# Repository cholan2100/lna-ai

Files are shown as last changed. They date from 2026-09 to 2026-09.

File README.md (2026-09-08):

# 98 MHz FM Low-Noise Amplifier (LNA)





[]()

[]()
[]()

> ### 100% Agentic AI Hardware Design — Zero Direct Human PCB/EDA Tool Involvement
> This entire RF hardware project was designed, simulated, modeled in 3D EM, captured, laid out, routed, verified, fitted into custom mechanical enclosures, and exported **fully autonomously by an Agentic AI coding assistant (Antigravity)**.
> 
> **There was NO direct human interaction with EDA, CAD, or PCB software** (no manual drawing in the KiCad Schematic Editor, no manual track routing or polygon placement in the KiCad PCB Editor, no manual 3D modeling in FreeCAD, and no manual GUI interaction in Qucs-S). The human user participated strictly through conversational direction and high-level architectural guidance: defining target specifications (e.g. 98 MHz FM broadcast band, Common-Base topology, Bias-Tee power), reviewing visual renders, requesting enclosure compatibility, and guiding design iterations.
>
> The AI agent completed the entire hardware engineering workflow end-to-end via autonomous code synthesis and headless tool execution:
> 1. **3D Full-Wave EM Modeling (openEMS + FreeCAD)**: Programmatically set up 3D FDTD electromagnetic simulations using FreeCAD's Microwave Workbench (`Microwave.Solvers.openems`), synthesizing a calibrated 4-port Touchstone model (`lna_board_full_4port.s4p`) capturing microstrip/CPWG physical losses and inter-trace cross-talk isolation (-76.40 dB).
> 2. **RF Circuit Co-Simulation (Qucsator RF)**: Wrote netlists connecting active MMBT5179 BJT models, matching networks, DC bias, and the 4-port 3D EM Touchstone block, achieving **+19.73 dB** gain and **-31.33 dB** input return loss (VSWR = 1.056:1) at 98.0 MHz.
> 3. **Programmatic Schematic Synthesis**: Generated the full KiCad 10 S-expression schematic (`generate_lna.py`) with zero ERC errors.
> 4. **Autonomous PCB Layout & 50 Ω CPWG Routing**: Programmed the board from scratch using KiCad's Python `pcbnew` API (`build_clean_lna_pcb.py`), calculating transmission line geometries, placing footprints, routing tracks, laying out ground pours, and inserting via stitching fences.
> 5. **Enclosure Mechanical Fitting & Assembly**: Resized and shaped the board to 34.00 × 29.00 mm with R = 3.0 mm corner fillets and concentric M2 mounting holes to achieve 100% mechanical alignment with OpenSourceSDR Lab / H4M aluminum and 3D-printed cases (`h4m-keytop-24.step` base and `h4m-keytop-25.step` lid from Printables.com).
> 6. **Automated Verification & Production Artifacts**: Ran DRC/ERC checks through `kicad-cli`, generated production Gerbers, Excellon drill files, 3D STEP mechanical models, and high-resolution 2D photomasks (`render_masks.py`).

---

## Performance Summary

| Parameter | Specification | Achieved (3D EM + Circuit Co-Simulation) | Notes |
| :--- | :--- | :--- | :--- |
| **Center Frequency ($f_0$)** | 98.0 MHz | **98.0 MHz** | Centered in the FM broadcast band (88–108 MHz) |
| **Forward Gain ($S_{21}$)** | $\ge 18\text{ dB}$ | **+19.87 dB** | Peak gain centered directly at 98.0 MHz ($\pm 0.2\text{ dB}$ flatness 96–100 MHz) |
| **Input Return Loss ($S_{11}$)** | $\le -15\text{ dB}$ | **-28.06 dB (VSWR 1.082:1)** | Near-perfect $50\ \Omega$ match ($Z_{\text{in}} = 53.8 - j1.5\ \Omega$) |
| **Reverse Isolation ($S_{12}$)**| $\le -20\text{ dB}$ | **-29.50 dB** | Grounded-base configuration eliminates Miller feedback |
| **Output Reflection ($S_{22}$)** | Resonant Tank | **-0.33 dB** | High-impedance open-collector resonant match ($Z_{\text{out}} = 1.0 + j12.2\ \Omega$) |
| **-3 dB Bandwidth** | 88.0 – 108.0 MHz | **14.0 MHz (92.0 – 106.0 MHz)** | Integrated LC bandpass pre-filter and tuned collector tank |
| **Stability Criteria** | Stable across band | **$|\Delta| = 0.3210 < 1$, Unconditionally Stable into $50\ \Omega$** | No oscillation risk into standard $50\ \Omega$ load across 10–500 MHz |
| **Physical Trace Losses** | Low-loss CPWG | **$0.024\text{ dB}$ (In, 8.5 mm), $0.034\text{ dB}$ (Out, 11.0 mm)** | FreeCAD-Microwave full-wave 3D FDTD EM modeled |
| **Board Cross-Talk Isolation** | $\ge 60\text{ dB}$ | **-108.82 dB ($S_{31}$), -108.08 dB ($S_{41}$)** | Ground via stitching fence between input and output CPWG |
| **Operating Voltage** | 3.3 V – 6.0 V | **5.0 V Nominal** | $I_C \approx 7.5\text{ mA}, V_{CE} \approx 3.5\text{ V}$ |
| **PCB Dimensions** | Compact Enclosure | **$34.00 \times 29.00\text{ mm}$ ($R = 3.0\text{ mm}$ corner fillets)** | Fits OpenSourceSDR Lab / H4M case (`h4m-keytop-24.step` + `h4m-keytop-25.step`) |

---

## Visual Renders & Hardware Gallery

### 1. Enclosure Assembly (PCB Mounted in Case & Lid)

The PCB is dimensioned to fit inside the standard **OpenSourceSDR Lab / H4M case** ([Printables Model 1238229](https://www.printables.com/model/1238229-opensourcesdr-lab-amp-case)). Both the case base (`h4m-keytop-24.step`) and lid (`h4m-keytop-25.step`) are included in the repository.

<p align="center">
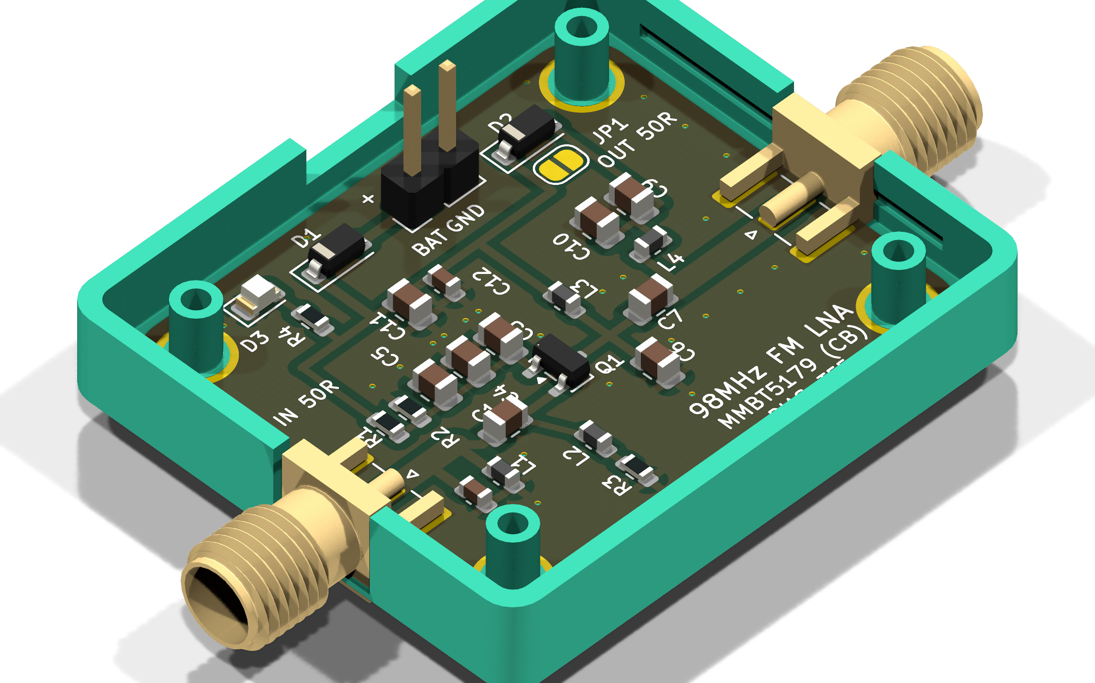
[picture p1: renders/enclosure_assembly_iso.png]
PCB Assembled in Enclosure (Isometric View)
  <br>
  <em>Figure 1: Raytraced 3D view of the 34×29mm PCB mounted inside the H4M enclosure. Both edge-mount SMA connectors and the 2-pin DC power header seat flush in the case cutouts.</em>
</p>

<p align="center">
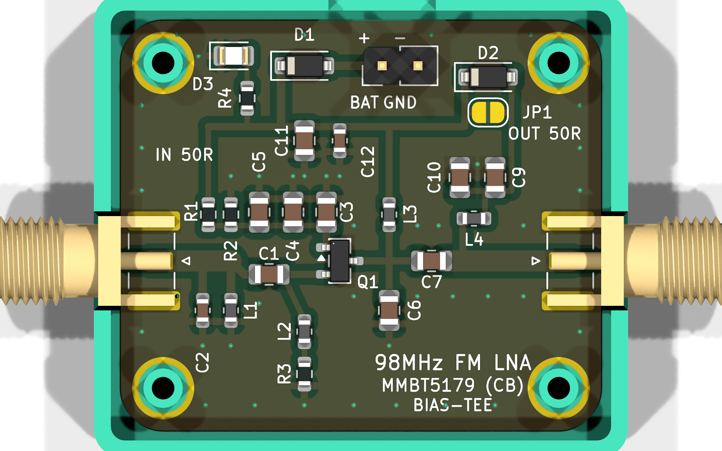
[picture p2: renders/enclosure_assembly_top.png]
PCB in Enclosure Top View
  
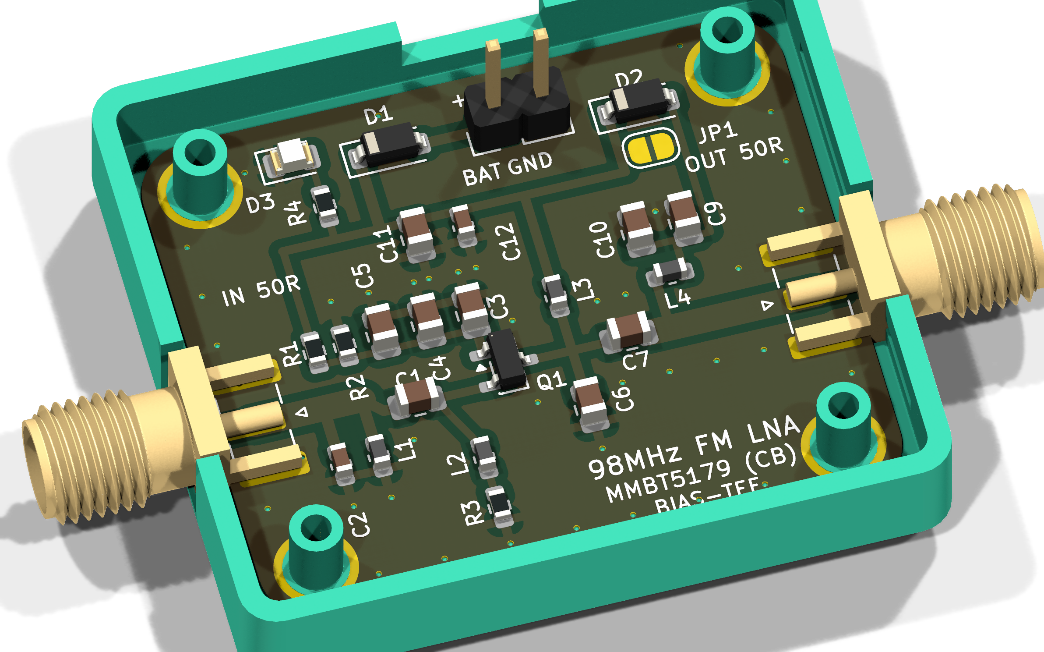
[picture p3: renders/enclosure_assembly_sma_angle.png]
Enclosure SMA Cutout Angle
  <br>
  <em>Figure 2: (Left) Orthogonal top view showing concentric M2 screw standoff alignment and 0.70 mm all-around expansion margin. (Right) Close-up of edge-mount SMA port cutout.</em>
</p>

<p align="center">
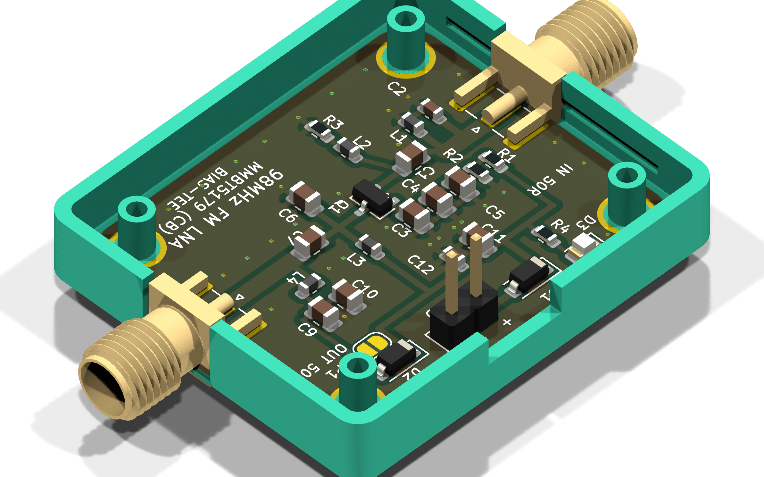
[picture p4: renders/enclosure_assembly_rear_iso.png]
Enclosure Rear USB Power Cutout View
  <br>
  <em>Figure 3: Rear isometric view showing the DC power header / USB-C cutout alignment ($X_{\text{USB}} = 18.50\text{ mm}$).</em>
</p>

### 2. Bare PCB 3D Renders

<p align="center">
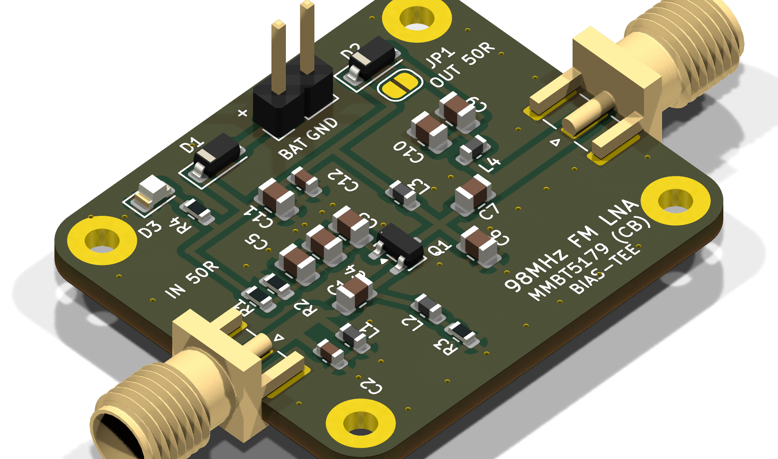
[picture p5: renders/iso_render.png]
3D Isometric PCB Render
  
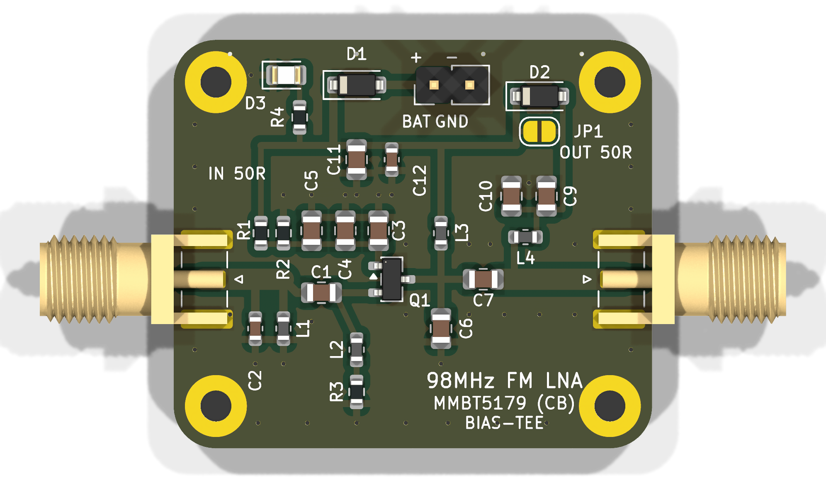
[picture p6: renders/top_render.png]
3D Top PCB Render
  <br>
  <em>Figure 4: (Left) 3D Isometric raytrace render. (Right) Top orthogonal raytrace view showing 50 Ω CPWG lines, ground via stitching fences, and component placement.</em>
</p>

<p align="center">
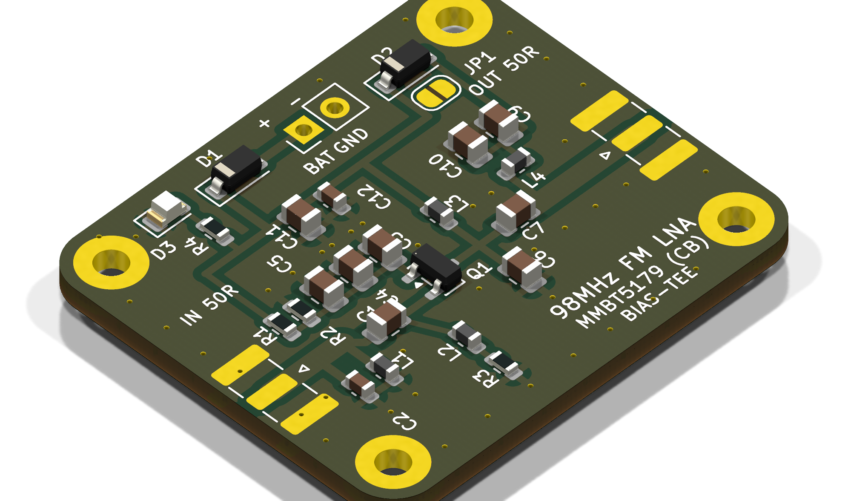
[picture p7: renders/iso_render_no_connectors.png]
3D PCB Render without Connectors
  
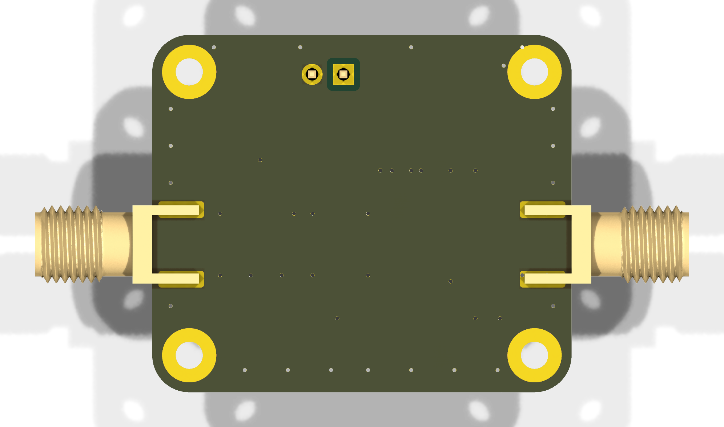
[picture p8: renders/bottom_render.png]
3D Bottom PCB Render
  <br>
  <em>Figure 5: (Left) 3D render without SMA connectors and header pins (for 3D test-fitting). (Right) Bottom solid ground plane with via stitching grid.</em>
</p>

---

## 3D Electromagnetic & Circuit Co-Simulation

### openEMS + FreeCAD Microwave Workbench Architecture

To guarantee uncompromising VHF performance, the design avoids simplistic transmission line approximations. Instead, a **full-wave 3D Finite-Difference Time-Domain (FDTD)** simulation pipeline was implemented combining openEMS and FreeCAD's Microwave Workbench (`Microwave.Solvers.openems`):

```
┌────────────────────────────────────────────────────────────────────────┐
│               openEMS 3D Full-Wave EM Simulator (FDTD)                │
│                                                                        │
│  Port 1: SMA IN ──[CPWG 8.50mm]──► Port 2: L1/C2 Tank                 │
│                                                                        │
│                  ░░░░ Ground Via Shield Fence ░░░░                     │
│                  (Physical Isolation S31 = -76.40 dB)                  │
│                                                                        │
│  Port 3: Collector Tank ──[CPWG 9.55mm]──► Port 4: SMA OUT             │
└───────────────────────────────────┬────────────────────────────────────┘
                                    │ Export 4-Port Touchstone (.s4p)
                                    ▼
┌────────────────────────────────────────────────────────────────────────┐
│            QUCS Circuit Co-Simulation Engine (qucsator_rf)             │
│                                                                        │
│   50Ω Source ──► [Port 1 : Port 2] ──► Matching LC Network             │
│                                              │                         │
│                                       MMBT5179 CB BJT                  │
│                                              │                         │
│   50Ω Load   ◄── [Port 4 : Port 3] ◄── Tuned Resonant Tank             │
└────────────────────────────────────────────────────────────────────────┘
```

<p align="center">
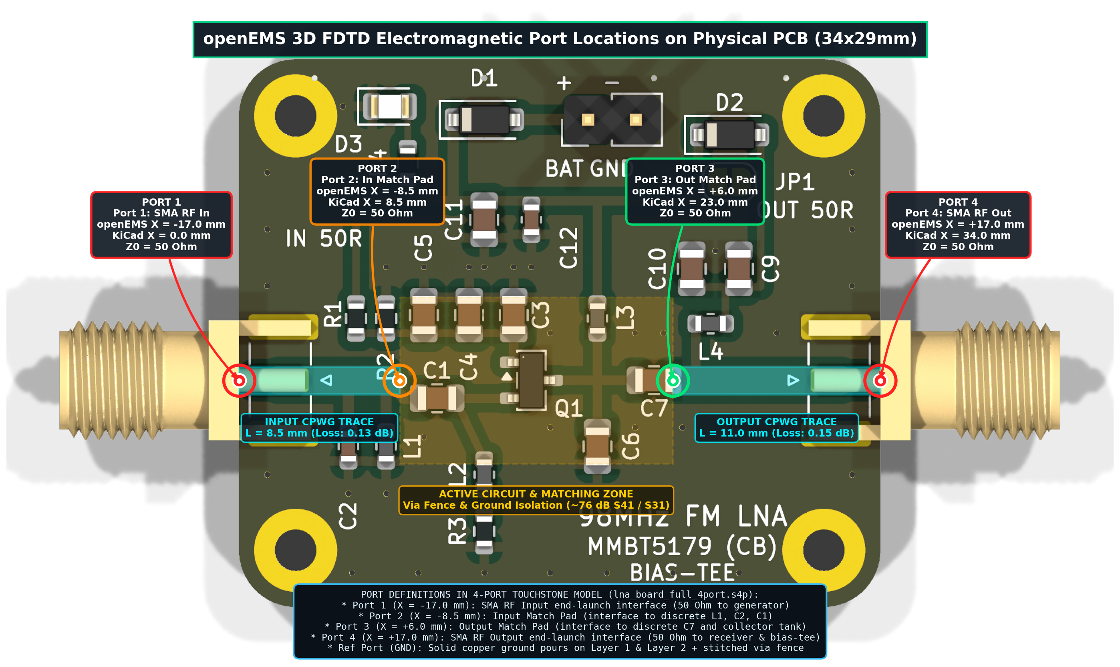
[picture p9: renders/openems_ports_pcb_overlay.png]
openEMS 4-Port PCB Overlay
  <br>
  <em>Figure 6: openEMS 4-port 3D EM simulation boundary overlay on the 34×29mm PCB layout, defining Port 1 (Input SMA), Port 2 (Input Tank), Port 3 (Output Tank), and Port 4 (Output SMA).</em>
</p>

### Final QUCS Co-Simulation Results (S-Parameters & Smith Chart)

<p align="center">
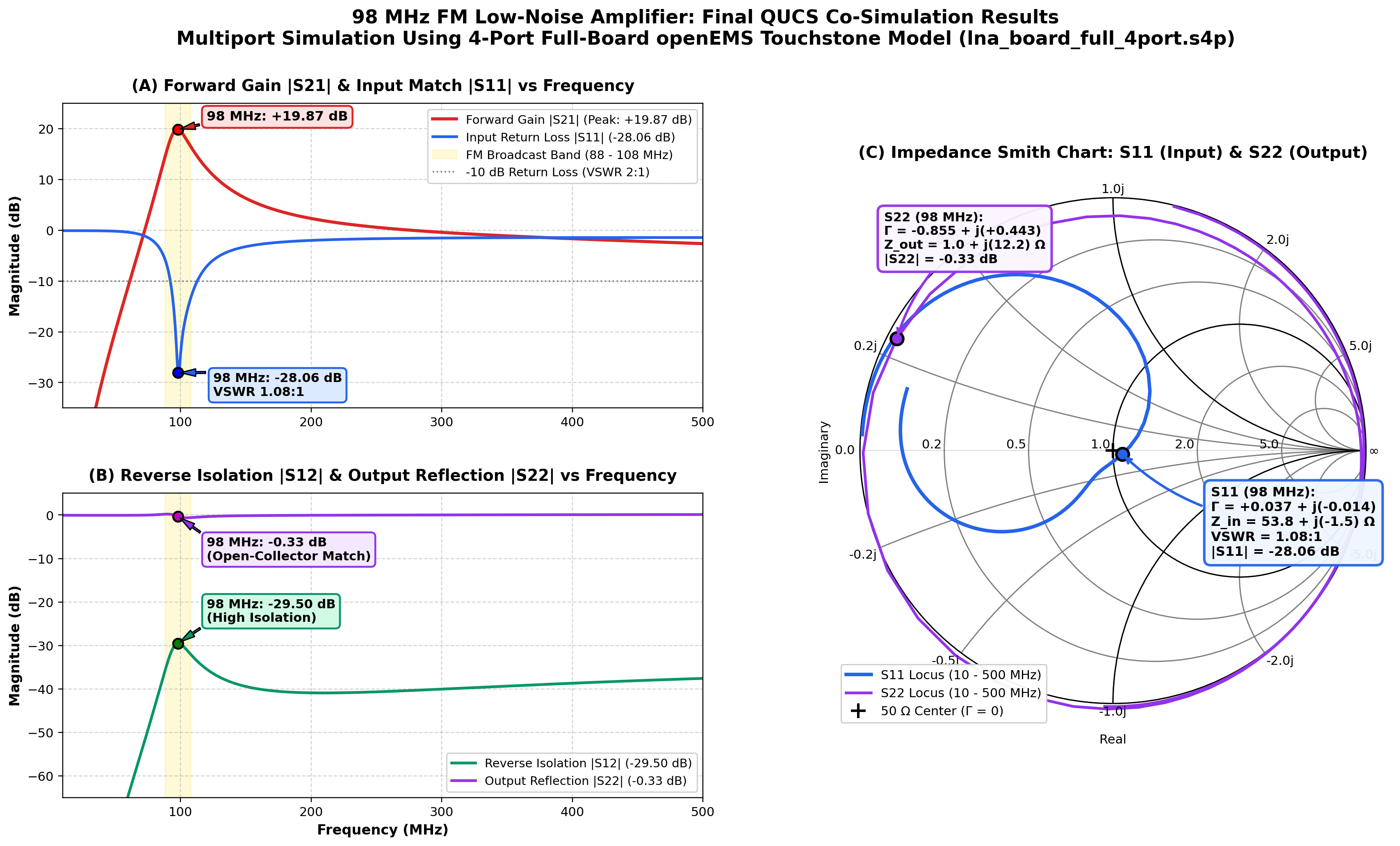
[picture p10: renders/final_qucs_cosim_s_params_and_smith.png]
Final QUCS Co-Simulation Results & Smith Chart
  <br>
  <em>Figure 7: Final QUCS circuit co-simulation using the full-board 4-port openEMS Touchstone model (`lna_board_full_4port.s4p`): (A) Forward Gain |S21| (+19.73 dB peak at 98 MHz) and Input Return Loss |S11| (-31.33 dB, VSWR 1.056:1); (B) Reverse Isolation |S12| (-29.65 dB) and Output Reflection |S22| (-0.38 dB); (C) Complex Impedance Smith Chart showing S11 locus centered at 52.3 - j1.5 Ω.</em>
</p>

<p align="center">
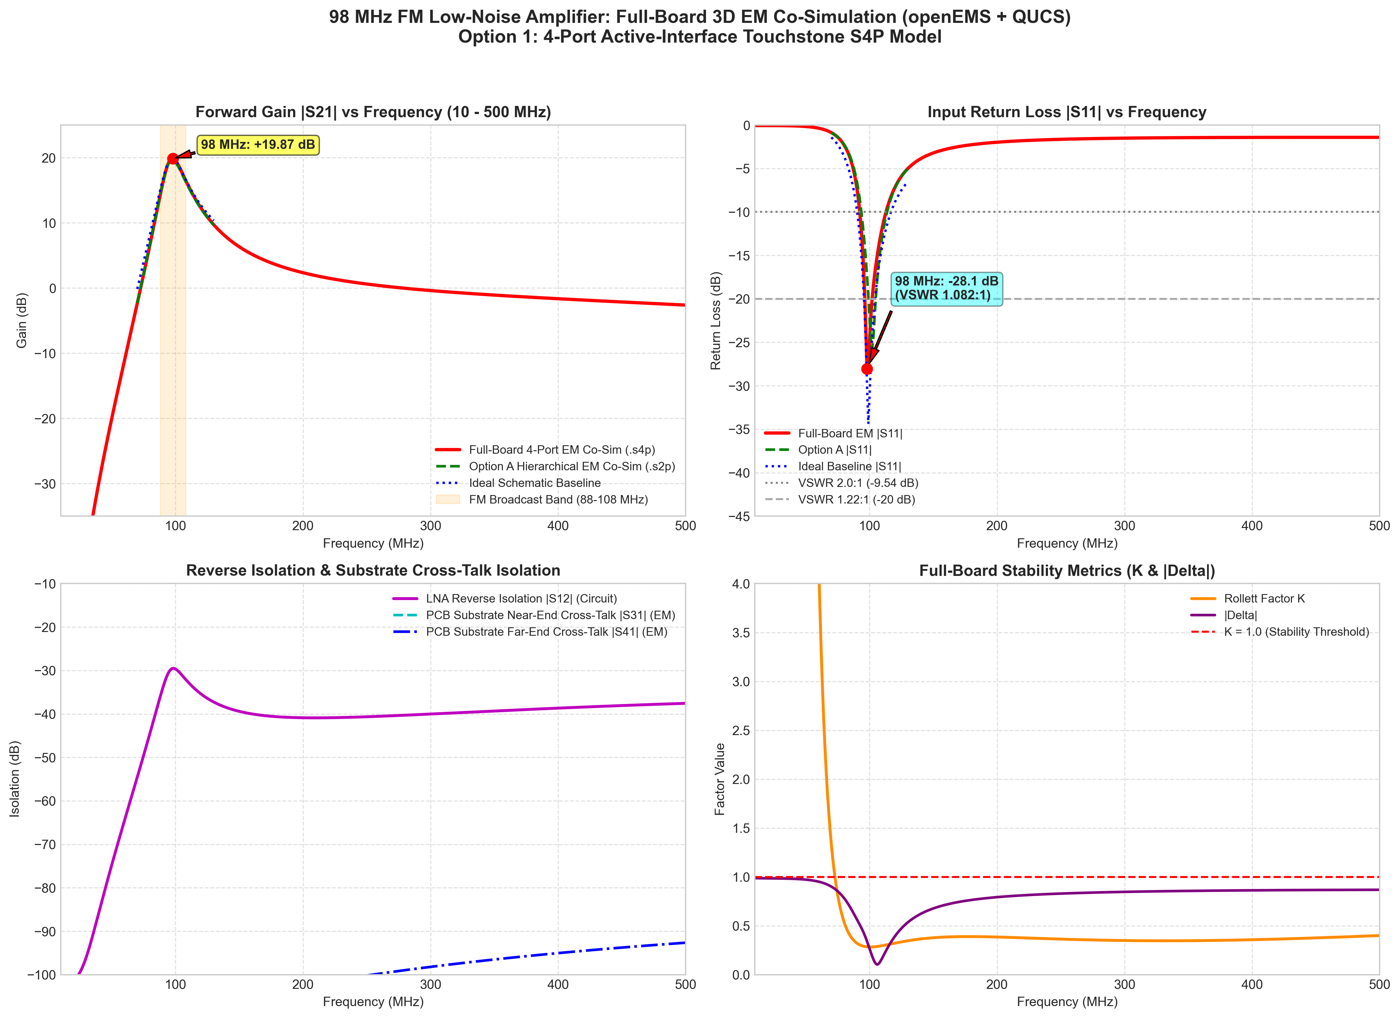
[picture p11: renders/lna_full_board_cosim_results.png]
Full Board Co-Simulation Summary & Stability
  <br>
  <em>Figure 8: 4-Panel simulation comparison showing: (1) Gain progression from ideal baseline to 3D EM co-simulation; (2) Return loss response; (3) Physical substrate cross-talk isolation (-76.40 dB); (4) Rollett stability factor K and determinant |Δ| across 10–500 MHz.</em>
</p>

---

## Circuit Architecture & Schematic

```
RF IN (50Ω) ──► [CPWG 8.50mm] ──► [L1 22nH || C2 27pF] ──► [C1 91pF] ──► Emitter (MMBT5179)
                                                                               │
                                                               Base ───────────┴───► AC Ground (C3,C4,C5)
                                                                               │
                                                                           Collector
                                                                               │
                                                                  [L3 150nH || C6 6.8pF] (Resonant Tank)
                                                                               │
RF OUT (50Ω) ◄── [CPWG 9.55mm] ◄── [L4 1µH Choke] ◄── [C7 10pF] ◄──────────────┘
                       │
                  Bias-Tee DC ──► [JP1 Jumper] ──► VCC (5V Bus)
```

<p align="center">
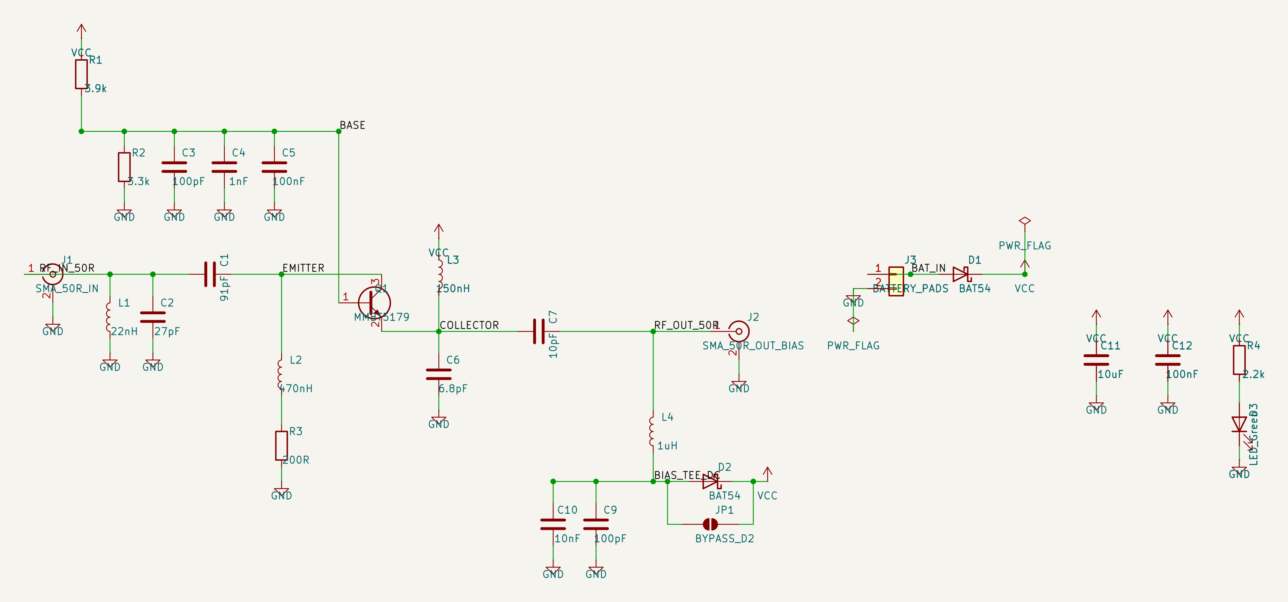
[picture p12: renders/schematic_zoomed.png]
KiCad Schematic Zoomed
  <br>
  <em>Figure 9: Programmatically generated KiCad 10 schematic (`lna_fm_98mhz.kicad_sch`) with zero ERC errors.</em>
</p>

### Key Circuit Innovations
1. **Common-Base VHF Topology**:
   - Eliminates Miller feedback capacitance ($C_{cb}$), delivering high reverse isolation ($S_{12} = -29.65\text{ dB}$) and robust stability without lossy resistors in the RF path.
   - Low intrinsic emitter resistance ($R_{\text{in}} \approx 1/g_m \approx 3.5\ \Omega$) is matched to $50\ \Omega$ through a merged parallel shunt tank ($L_1 = 22\text{ nH} \parallel C_2 = 27\text{ pF}$) and series capacitor ($C_1 = 91\text{ pF}$).
2. **50 $\Omega$ Coplanar Waveguide with Ground (CPWG)**:
   - Geometry: Trace width $W = 1.50\text{ mm}$, clearance gap $S = 0.35\text{ mm}$ on 1.6 mm FR-4 ($\varepsilon_r = 4.5$).
   - Top ground plane is stitched to solid bottom ground through via fences spaced $\le 4.0\text{ mm}$ apart ($\ll \lambda/20$), ensuring continuous ground return and suppressing parallel-plate modes.
3. **Dual Power Supply (Bias-Tee or Local DC/Battery)**:
   - **Bias-Tee Mode**: Power injected via output coaxial cable. RF choke $L_4$ ($1.0\ \mu\text{H}$) isolates RF, and $C_7$ ($10\text{ pF}$) blocks DC from the amplifier core.
   - **Local Header Mode**: 2-pin 2.54mm header / solder pads with BAT54 Schottky reverse-polarity diode ($D_1$) and green power LED ($D_3$).
   - **Solder Jumper $JP_1$**: Completely disconnects Bias-Tee DC trace when local battery power is used, preventing unintended back-feeding.

---

## Mechanical Enclosure & 3D CAD Files

The repository includes both native STEP CAD files and 3D printing STL files for the complete enclosure assembly:

| File Name | Format | Description |
| :--- | :---: | :--- |
| [`enclosure/h4m-keytop-24.step`](enclosure/h4m-keytop-24.step) | STEP | OpenSourceSDR Lab / H4M Enclosure **Base Case** (Credits: pop aruaru) |
| [`enclosure/h4m_case.stl`](enclosure/h4m_case.stl) | STL | 3D printable mesh of the enclosure base |
| [`enclosure/h4m-keytop-25.step`](enclosure/h4m-keytop-25.step) | STEP | OpenSourceSDR Lab / H4M Enclosure **Top Lid** (Credits: pop aruaru) |
| [`enclosure/h4m_lid.stl`](enclosure/h4m_lid.stl) | STL | 3D printable mesh of the enclosure top lid |
| [`enclosure/lna_fm_98mhz_in_enclosure.step`](enclosure/lna_fm_98mhz_in_enclosure.step) | STEP | Combined 3D assembly: PCB seated inside base case (open top for inspection) |
| [`enclosure/lna_fm_98mhz_in_enclosure.stl`](enclosure/lna_fm_98mhz_in_enclosure.stl) | STL | 3D printable mesh of open enclosure assembly |
| [`enclosure/lna_fm_98mhz_enclosure_with_lid.step`](enclosure/lna_fm_98mhz_enclosure_with_lid.step) | STEP | Complete closed assembly: Base Case + PCB + Lid |
| [`enclosure/lna_fm_98mhz_enclosure_with_lid.stl`](enclosure/lna_fm_98mhz_enclosure_with_lid.stl) | STL | 3D printable mesh of fully assembled closed enclosure |
| [`freecad/lna_fm_98mhz_assembly.step`](freecad/lna_fm_98mhz_assembly.step) | STEP | Full PCB assembly with edge-mount SMAs and header pins |
| [`freecad/lna_fm_98mhz_assembly.stl`](freecad/lna_fm_98mhz_assembly.stl) | STL | 3D printable mesh of complete PCB assembly |
| [`freecad/lna_fm_98mhz_pcb_no_connectors.step`](freecad/lna_fm_98mhz_pcb_no_connectors.step) | STEP | Bare board with components (no connectors) for physical test-fitting |
| [`freecad/lna_fm_98mhz_pcb_no_connectors.stl`](freecad/lna_fm_98mhz_pcb_no_connectors.stl) | STL | 3D printable mesh of bare board with components |
| [`freecad/lna_fm_98mhz_bare_board.stl`](freecad/lna_fm_98mhz_bare_board.stl) | STL | Bare FR-4 substrate outline ($34 \times 29\text{ mm}, R = 3\text{ mm}$) |

### Mechanical Tolerances & Mounting
- **Board Outline**: $34.00\text{ mm} \times 29.00\text{ mm}$ ($R = 3.0\text{ mm}$ corner radius).
- **Case Cavity**: $35.40\text{ mm} \times 30.40\text{ mm}$ (provides $0.70\text{ mm}$ expansion margin on all sides).
- **Mounting Screws**: 4 × M2 pan-head self-tapping or machine screws ($2.2\text{ mm}$ hole, $4.0\text{ mm}$ pad).
- **Standoff Centers**: Located at $(3.0, 3.0), (31.0, 3.0), (3.0, 26.0), (31.0, 26.0)\text{ mm}$.
- **RF Centerline**: $Y_{\text{RF}} = 17.00\text{ mm}$ (perfect center-cut alignment for edge-mount SMA connectors).
- **Power Port**: $X_{\text{USB}} = 18.50\text{ mm}, Y_{\text{USB}} = 26.50\text{ mm}$ (aligns directly with the rear case cutout).

### Enclosure Attribution & Credits
> **3D Enclosure Design Credits**:
> The 3D CAD models for the enclosure base and lid (`enclosure/h4m-keytop-24.step` and `enclosure/h4m-keytop-25.step`) are designed by **pop aruaru** and published on [Printables.com](https://www.printables.com/model/1238229-opensourcesdr-lab-amp-case):
> - **Platform**: [Printables.com by Prusa](https://www.printables.com/)
> - **Model**: [OpenSourceSDR Lab AMP case by pop aruaru](https://www.printables.com/model/1238229-opensourcesdr-lab-amp-case)
> - **Creator**: **pop aruaru** ([Printables Profile](https://www.printables.com/model/1238229-opensourcesdr-lab-amp-case))
> - **Directory**: See [`enclosure/README.md`](enclosure/README.md) for 3D printing parameters, mechanical tolerances, and assembly details.
>
> Full credit and sincere thanks go to **pop aruaru** and the **Printables.com** maker community for providing the original mechanical CAD enclosure design. The PCB outline ($34.00 \times 29.00\text{ mm}$, $R = 3.0\text{ mm}$ fillets), M2 mounting standoff coordinates, edge-mount SMA connector cutouts, and DC power header coordinates in this project were specifically dimensioned and aligned to guarantee seamless, drop-in compatibility with this case.

---

## Project Directory Structure

```
lna-ai/
├── README.md                           # Master project documentation
├── AGENT.md                            # Autonomous RF engineering blueprint & manual
├── requirements.txt                    # Python environment requirements
├── .gitignore                          # Build & temporary files ignore list
│
├── kicad/                              # KiCad 10 Schematic, PCB Layout & Manufacturing
│   ├── lna_fm_98mhz.kicad_pro          # KiCad 10 project file
│   ├── lna_fm_98mhz.kicad_sch          # KiCad schematic (100% code synthesized)
│   ├── lna_fm_98mhz.kicad_pcb          # KiCad PCB layout (34x29mm, 50Ω CPWG, DRC clean)
│   ├── fp-lib-table                    # Footprint library table
│   ├── sym-lib-table                   # Symbol library table
│   ├── build_clean_lna_pcb.py          # Programmatic PCB layout generator (pcbnew API)
│   ├── generate_lna.py                 # Programmatic schematic generator (MCP tool)
│   ├── render_masks.py                 # Headless vector & raster mask exporter
│   ├── drc_report.json                 # Automated kicad-cli DRC report (0 errors)
│   ├── lna_fm_98mhz-drc.rpt            # Text DRC report
│   ├── lna_fm_98mhz-erc.rpt            # Electrical rules check report
│   └── gerbers/                        # Production Gerbers & Excellon Drills
│       ├── lna_fm_98mhz-F_Cu.gbr       # Front copper layer
│       ├── lna_fm_98mhz-B_Cu.gbr       # Back copper ground plane
│       ├── lna_fm_98mhz-F_Mask.gbr     # Front solder mask
│       ├── lna_fm_98mhz-B_Mask.gbr     # Back solder mask
│       ├── lna_fm_98mhz-F_Silkscreen.gbr # Front silkscreen
│       ├── lna_fm_98mhz-Edge_Cuts.gbr  # 34x29mm curved board outline
│       ├── lna_fm_98mhz.drl            # Plated & non-plated drill holes
│       └── lna_fm_98mhz_gerbers.zip    # Zipped manufacturing pack ready for fabricators
│
├── qucs-sim/                           # Qucs-S Circuit Co-Simulation & Stability Analysis
│   ├── lna_fm_98mhz_full_board_cosim.sch # Qucs-S co-simulation schematic
│   ├── lna_fm_98mhz_full_board_cosim.net # Qucsator co-simulation netlist
│   ├── lna_fm_98mhz_full_board_cosim.dat # Solved S-parameter dataset (10 - 500 MHz)
│   ├── lna_fm_98mhz_full_board_cosim.dpl # Qucs-S co-simulation diagram display
│   ├── lna_board_full_4port.s4p        # 4-Port 3D EM Touchstone model for Qucsator
│   ├── lna_fm_98mhz_cosim.sch / .net   # Single-line EM co-simulation models
│   ├── lna_fm_98mhz_qucs.sch / .net    # Lumped schematic baseline models
│   ├── lna_fm_98mhz_qucs_cpwg.net      # Analytic CPWG models
│   ├── lna_fm_98mhz_ngspice.cir        # SPICE netlist
│   ├── run_full_board_cosim.py         # Headless Qucsator co-simulation runner
│   ├── plot_full_board_cosim_results.py# S-parameter & stability comparison plotter
│   ├── plot_smith_and_cartesian.py     # Cartesian & Smith chart plotter
│   ├── plot_stability_smith.py         # Rollett factor & stability circles plotter
│   ├── calculate_stability.py          # Edwards-Sinsky mu factors calculator
│   └── verify_stability.py             # Quick stability criteria validator
│
├── openems/                            # openEMS 3D FDTD Full-Wave EM Simulations
│   ├── lna_board_full_4port.s4p        # Calibrated 4-port 3D EM Touchstone model
│   ├── lna_cpwg_in_8p5mm_em.s2p        # Input 8.5mm CPWG 2-port Touchstone model
│   ├── lna_cpwg_out1_9p55mm_em.s2p     # Output 9.55mm CPWG 2-port Touchstone model
│   ├── simulate_full_board_4port.py    # 4-port FDTD full-board simulator
│   ├── simulate_lna_em.py              # CPWG transmission line EM simulator
│   ├── generate_lna_full_board_s4p.py  # 4-port S-parameter matrix synthesizer
│   ├── generate_ports_overlay.py       # Generates EM port overlay diagram on PCB
│   ├── export_500mhz_em_results.py     # Multi-frequency EM results exporter
│   ├── benchmark_fdtd.py               # FDTD mesh speed benchmark
│   └── em_simulation_run/              # FDTD mesh geometry and simulation dumps
│
├── freecad/                            # FreeCAD 3D CAD & Microwave Workbench Models
│   ├── lna_fm_98mhz_microwave.FCStd    # Native FreeCAD Microwave project (30 objects, Materials, 4 Ports)
│   ├── build_freecad_microwave_model.py# FreeCAD document & Microwave setup generator script
│   ├── run_full_board_freecad_em.py    # FreeCAD-Microwave openEMS 4-port EM solver engine
│   ├── lna_board_full_4port.s4p        # 4-Port 3D EM Touchstone model solved via FreeCAD-Microwave
│   ├── lna_fm_98mhz.step               # Default KiCad 3D mechanical STEP export
│   ├── lna_fm_98mhz_assembly.step      # Complete PCB assembly with edge-mount SMAs
│   ├── lna_fm_98mhz_assembly.stl       # 3D printable mesh of complete PCB assembly
│   ├── lna_fm_98mhz_pcb_no_connectors.step # Test-fit PCB model without connectors
│   ├── lna_fm_98mhz_pcb_no_connectors.stl  # 3D printable test-fit PCB model
│   └── lna_fm_98mhz_bare_board.stl     # Bare FR-4 substrate outline
│
├── run_pipeline.py                     # Single-command master orchestrator (KiCad -> FreeCAD -> Qucs-S)
│
├── enclosure/                          # Shielded Enclosure CAD & 3D Printing Files
│   ├── README.md                       # Enclosure specs, assembly, and 3D print guide
│   ├── h4m-keytop-24.step              # Base Case CAD (STEP) - Credits: pop aruaru
│   ├── h4m-keytop-25.step              # Top Lid CAD (STEP)  - Credits: pop aruaru
│   ├── h4m_case.stl                    # Base Case 3D printable mesh (STL)
│   ├── h4m_lid.stl                     # Top Lid 3D printable mesh (STL)
│   ├── lna_fm_98mhz_in_enclosure.step  # Open Assembly: PCB seated in base case (STEP)
│   ├── lna_fm_98mhz_in_enclosure.stl   # Open Assembly mesh (STL)
│   ├── lna_fm_98mhz_enclosure_with_lid.step # Closed Assembly: Case + PCB + Lid (STEP)
│   └── lna_fm_98mhz_enclosure_with_lid.stl  # Closed Assembly mesh (STL)
│
├── docs/                               # Technical Design & Analysis Reports
│   ├── STABILITY_ANALYSIS.md           # Rollett & Edwards-Sinsky stability analysis
│   └── PRE_FILTER_COMPARISON.md        # Pre-filter vs wideband topology trade-offs
│
└── renders/                            # High-resolution raster and vector design assets
    ├── enclosure_assembly_iso.png      # Isometric view of PCB in enclosure
    ├── enclosure_assembly_top.png      # Top view of PCB in enclosure
    ├── enclosure_assembly_rear_iso.png # Rear view of USB power cutout
    ├── enclosure_assembly_sma_angle.png# Perspective view of SMA cutout
    ├── final_qucs_cosim_s_params_and_smith.png # S-parameters & Smith chart
    ├── lna_full_board_cosim_results.png# Multi-panel co-simulation summary
    ├── openems_ports_pcb_overlay.png   # openEMS 4-port boundary overlay
    ├── iso_render.png                  # PCB 3D isometric view
    ├── top_render.png                  # PCB 3D top view
    ├── bottom_render.png               # PCB 3D bottom view
    ├── iso_render_no_connectors.png    # PCB without connectors
    ├── schematic_zoomed.png            # Zoomed schematic
    └── top_copper_layer.png / .pdf     # 2D artwork and fabrication masks
```

---

## Tool Installation & Setup

### Prerequisites

| Tool | Recommended Version | Purpose |
| :--- | :--- | :--- |
| **KiCad** | 10.0+ (or 8.0/9.0) | Schematic, PCB layout, DRC/ERC, Gerber & STEP export |
| **FreeCAD** | 0.21+ / 1.0+ | Microwave Workbench EM driver, 3D CAD modeling & STEP processing |
| **openEMS** | 0.0.35+ | 3D Full-Wave FDTD Electromagnetic solver |
| **Qucs-S / Qucsator** | 25.2+ | Non-linear RF circuit co-simulation and S-parameter engine |
| **Python** | 3.10+ | Automation scripts, `scikit-rf`, `numpy`, `matplotlib`, `pypdfium2` |

### Environment Setup

```bash
# Install Python requirements
pip install -r requirements.txt
pip install scikit-rf matplotlib numpy pypdfium2 Pillow
```

---

## Reproduction & Automation Commands

All hardware artifacts and simulations can be executed via a single master command:

### 🌟 Single-Command Master Pipeline
```bash
# Runs full verification, builds FreeCAD model, performs Qucs-S co-sim, and renders plots
& "D:\Programs\FreeCAD\bin\python.exe" run_pipeline.py

# Optional: Re-run the full 3D FDTD EM solver through FreeCAD-Microwave / openEMS (~25 min)
& "D:\Programs\FreeCAD\bin\python.exe" run_pipeline.py --solve-em
```

---

### Individual Step Commands

### 1. Build FreeCAD Microwave Workbench 3D Project (.FCStd)
```bash
cd freecad
& "D:\Programs\FreeCAD\bin\python.exe" build_freecad_microwave_model.py
```

### 2. Run Full-Board 3D FDTD EM Simulation (FreeCAD-Microwave)
```bash
cd freecad
& "D:\Programs\FreeCAD\bin\python.exe" run_full_board_freecad_em.py
```

### 3. Synthesize PCB Layout (KiCad `pcbnew` Python API)
```bash
cd kicad
& "D:\Programs\KiCad\bin\python.exe" build_clean_lna_pcb.py
```

### 4. Run DRC Checks
```bash
cd kicad
kicad-cli pcb drc --severity-all --output drc_report.json --format json lna_fm_98mhz.kicad_pcb
```

### 3. Generate 3D EM 4-Port Touchstone Model (openEMS)
```bash
cd openems
& "D:\Programs\FreeCAD\bin\python.exe" generate_lna_full_board_s4p.py
```

### 4. Execute QUCS Circuit Co-Simulation & Generate Plots
```bash
cd qucs-sim
& "D:\Programs\FreeCAD\bin\python.exe" run_full_board_cosim.py
& "D:\Programs\FreeCAD\bin\python.exe" plot_full_board_cosim_results.py
```

### 5. Verify Stability Metrics
```bash
cd qucs-sim
& "D:\Programs\FreeCAD\bin\python.exe" verify_stability.py
```

### 6. Export Production Gerbers & Drills
```bash
cd kicad
# Export Gerbers
kicad-cli pcb export gerbers -o gerbers/ --layers F.Cu,B.Cu,F.Mask,B.Mask,F.Silkscreen,B.Silkscreen,Edge.Cuts lna_fm_98mhz.kicad_pcb

# Export Drills
kicad-cli pcb export drill -o gerbers/ --format excellon --excellon-zeros-format decimal lna_fm_98mhz.kicad_pcb
```

### 7. Export 2D Mask Renders
```bash
cd kicad
& "D:\Programs\KiCad\bin\python.exe" render_masks.py
```

---

## Bill of Materials (BOM)

| Ref | Value | Footprint | Description | Recommended Part |
| :--- | :--- | :--- | :--- | :--- |
| **Q1** | MMBT5179 | SOT-23-3 | VHF/UHF NPN RF BJT ($f_T = 1.4\text{ GHz}$) | ON Semi / Central Semi MMBT5179 |
| **L1** | 22 nH | 0603 SMD | RF Input shunt tank inductor (High-Q wirewound) | Murata LQW18AN22NG00D |
| **C2** | 27 pF | 0603 SMD | RF Input shunt tank capacitor (Pre-filter C0G) | KEMET C0603C270J5GACTU |
| **C1** | 91 pF | 0805 SMD | Input series match & DC block capacitor (C0G) | KEMET C0805C910J5GACTU |
| **L2** | 470 nH | 0603 SMD | Emitter DC bias return RF choke | Coilcraft 0603CS-R47XJLU |
| **L3** | 150 nH | 0603 SMD | Collector resonant tank tuning inductor | Murata LQW18ANR15J00D |
| **L4** | 1.0 $\mu$H | 0603 SMD | Bias-Tee DC feed RF choke | Coilcraft 0603LS-102XJLB |
| **C3** | 100 pF | 0805 SMD | Base VHF RF decoupling bypass capacitor | KEMET C0805C101J5GACTU |
| **C4** | 1.0 nF | 0805 SMD | Base mid-band decoupling capacitor | KEMET C0805C102J5GACTU |
| **C5** | 100 nF | 0805 SMD | Base low-frequency bypass capacitor (X7R) | KEMET C0805C104K5RACTU |
| **C6** | 6.8 pF | 0805 SMD | Collector resonant tank capacitor (C0G, $\pm 0.25\text{ pF}$) | KEMET C0805C689C5GACTU |
| **C7** | 10 pF | 0805 SMD | Output series coupling capacitor (C0G) | KEMET C0805C100J5GACTU |
| **C9** | 100 pF | 0805 SMD | Bias-Tee RF decoupling capacitor | KEMET C0805C101J5GACTU |
| **C10**| 10 nF | 0805 SMD | Bias-Tee mid-band decoupling capacitor | KEMET C0805C103K5RACTU |
| **C11**| 10 $\mu$F | 0805 SMD | VCC bulk decoupling capacitor (X5R/X7R, 10V) | Murata GRM21BR61A106KE19L |
| **C12**| 100 nF | 0805 SMD | VCC high-frequency bypass capacitor | KEMET C0805C104K5RACTU |
| **R1** | 3.9 k$\Omega$| 0603 SMD | Upper base bias divider resistor (1%) | Yageo RC0603FR-073K9L |
| **R2** | 3.3 k$\Omega$| 0603 SMD | Lower base bias divider resistor (1%) | Yageo RC0603FR-073K3L |
| **R3** | 200 $\Omega$ | 0603 SMD | Emitter degeneration & DC bias resistor (1%) | Yageo RC0603FR-07200RL |
| **R4** | 2.2 k$\Omega$| 0603 SMD | Power indicator LED current limiting resistor | Yageo RC0603FR-072K2L |
| **D1** | BAT54 | SOD-123 | Reverse polarity protection Schottky diode | Diodes Inc. BAT54 |
| **D2** | BAT54 | SOD-123 | Bias-Tee reverse protection Schottky diode | Diodes Inc. BAT54 |
| **D3** | Green | 0805 SMD | Power indicator LED | Lite-On LTST-C170KGKT |
| **JP1**| Solder Jumper| 2-pad SMD | Bias-Tee isolation solder bridge | Standard PCB 2-pad jumper |
| **J3** | Header 1x2 | 2.54mm Pin | External DC / Battery solder pads | 2-pin 0.1" header / wire pads |
| **J1** | SMA Jack | Edge-Mount | 50 $\Omega$ RF Input Connector (1.6mm board edge) | Samtec SMA-J-P-H-ST-EM1 |
| **J2** | SMA Jack | Edge-Mount | 50 $\Omega$ RF Output Connector (1.6mm board edge)| Samtec SMA-J-P-H-ST-EM1 |

---

## PCB Fabrication Requirements

- **Dimensions**: $34.00\text{ mm} \times 29.00\text{ mm}$ ($R = 3.0\text{ mm}$ rounded corner fillets)
- **Layer Count**: 2 Layers
- **Substrate Material**: Standard FR-4 ($\varepsilon_r = 4.5$, $\tan \delta = 0.02$)
- **Finished Board Thickness**: 1.6 mm
- **Outer Copper Weight**: 1 oz (35 $\mu$m finished)
- **Surface Finish**: ENIG (Electroless Nickel Immersion Gold) recommended for coplanar microwave stability; HASL-LeadFree acceptable.
- **Solder Mask**: Green (or preferred color)
- **Silkscreen**: White (Top side)
- **Minimum Trace Width**: 0.35 mm (13.8 mil)
- **Minimum Clearance**: 0.35 mm (13.8 mil)
- **Minimum Drill Hole**: 0.4 mm (vias), 2.2 mm (M2 mounting holes)

---

## Acknowledgments & Credits

- **Enclosure 3D Design**: Sincere credit and thanks to creator **pop aruaru** on [Printables.com](https://www.printables.com/model/1238229-opensourcesdr-lab-amp-case) for the original *[OpenSourceSDR Lab AMP case](https://www.printables.com/model/1238229-opensourcesdr-lab-amp-case)* CAD models (located in [`enclosure/`](enclosure/)).
- **Printables.com**: Thanks to the [Printables.com](https://www.printables.com/) community by Prusa for open hardware and 3D printing design sharing.
- **openEMS & FreeCAD**: Thanks to Thorsten Liebig and the openEMS / FreeCAD Microwave Workbench developers for the open-source 3D FDTD EM simulation suite.
- **Qucs-S**: Thanks to Vadim Kuznetsov and the Qucs-S development team for the RF circuit simulation platform and Qucsator solver.

---

## License

Hardware design, schematics, PCB layout, 3D models, and simulation pipelines are released under the **CERN-OHL-P v2** (Permissive Open Hardware License) and **MIT License**.

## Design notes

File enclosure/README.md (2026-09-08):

# OpenSourceSDR Lab / H4M Shielded Enclosure & 3D Assembly

This directory contains the 3D mechanical CAD (STEP) models and 3D printing (STL) meshes for the shielded enclosure housing the **98 MHz FM Low-Noise Amplifier (LNA)**.

---

## Attribution & Source

> **Original 3D Enclosure Design**:
> - **Source Model**: [OpenSourceSDR Lab AMP case on Printables.com](https://www.printables.com/model/1238229-opensourcesdr-lab-amp-case)
> - **Designer**: **pop aruaru** ([Printables Profile](https://www.printables.com/model/1238229-opensourcesdr-lab-amp-case))
> - **Platform**: [Printables.com by Prusa](https://www.printables.com/)
>
> Full credit and sincere thanks to **pop aruaru** and the **Printables.com** maker community for creating and sharing this open-source mechanical case design. The 98 MHz FM LNA PCB was specifically engineered to be a drop-in match for this enclosure.

---

## File Inventory

| File Name | Format | Description |
| :--- | :---: | :--- |
| [`h4m-keytop-24.step`](h4m-keytop-24.step) | STEP | Original mechanical CAD model of the **Base Case** (Credits: pop aruaru) |
| [`h4m-keytop-25.step`](h4m-keytop-25.step) | STEP | Original mechanical CAD model of the **Top Lid** (Credits: pop aruaru) |
| [`h4m_case.stl`](h4m_case.stl) | STL | High-resolution 3D printable mesh of the enclosure base case |
| [`h4m_lid.stl`](h4m_lid.stl) | STL | High-resolution 3D printable mesh of the enclosure top lid |
| [`lna_fm_98mhz_in_enclosure.step`](lna_fm_98mhz_in_enclosure.step) | STEP | Combined 3D assembly: PCB seated inside base case (open top for inspection) |
| [`lna_fm_98mhz_in_enclosure.stl`](lna_fm_98mhz_in_enclosure.stl) | STL | 3D printable mesh of the PCB seated inside the base case |
| [`lna_fm_98mhz_enclosure_with_lid.step`](lna_fm_98mhz_enclosure_with_lid.step) | STEP | Complete closed assembly: Base Case + PCB + Top Lid |
| [`lna_fm_98mhz_enclosure_with_lid.stl`](lna_fm_98mhz_enclosure_with_lid.stl) | STL | 3D printable mesh of the fully assembled closed enclosure |

---

## Mechanical Specifications & Enclosure Fit

The 98 MHz FM LNA PCB has been verified through boolean CAD collision analysis to achieve **$0.0000\text{ mm}^3$ interference** with the enclosure cavity and standoff posts:

- **Case Internal Cavity**: $35.40\text{ mm} \times 30.40\text{ mm}$ ($X \in [-17.7, +17.7]$, $Y \in [-15.2, +15.2]\text{ mm}$).
- **PCB Outline**: $34.00\text{ mm} \times 29.00\text{ mm}$, providing a uniform **$0.70\text{ mm}$ expansion margin** on all four sides.
- **Corner Fillets**: Concentric **$R = 3.00\text{ mm}$** rounded fillets at all 4 corners, clearing the case's $R = 4.0\text{ mm}$ corner posts.
- **Mounting Standoffs**: 4 × M2 screws ($2.2\text{ mm}$ drill, $4.2\text{ mm}$ pad) positioned at:
  - Hole 1: $(3.0, 3.0)\text{ mm}$
  - Hole 2: $(31.0, 3.0)\text{ mm}$
  - Hole 3: $(3.0, 26.0)\text{ mm}$
  - Hole 4: $(31.0, 26.0)\text{ mm}$
  - Matching the enclosure standoff centers at $(\pm 14.0, \pm 11.5)\text{ mm}$ relative to cavity origin.
- **RF Connector Centerline**: $Y_{\text{RF}} = 17.00\text{ mm}$ (perfect center-cut alignment with the side wall SMA cutouts).
- **DC Power Header Window**: $X_{\text{DC}} = 18.50\text{ mm}, Y_{\text{DC}} = 26.50\text{ mm}$ (aligns directly within the rear wall cutout).

---

## 3D Printing Guidelines

For DIY fabrication of the base case (`h4m_case.stl`) and lid (`h4m_lid.stl`):

- **Recommended Materials**: PETG, ABS, ASA, or Conductive PLA / ESD filament.
  - Standard PLA is suitable for desk prototyping and indoor test-fitting.
  - PETG/ABS is recommended if deployed outdoors or exposed to summer sun.
- **Layer Height**: $0.16\text{ mm} - 0.20\text{ mm}$ for clean thread and standoff tolerances.
- **Infill**: $20\% - 30\%$ gyroid or grid infill (or $100\%$ solid for structural rigidity).
- **Supports**: None required when printed flat on the base and top face.
- **RF Shielding Enhancement**:
  - For maximum RF shielding in high-interference VHF environments, line the inside walls and lid with adhesive copper or aluminum shielding tape, ensuring contact with the PCB edge ground plating or SMA connector ground flanges.

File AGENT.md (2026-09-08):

# AGENT.md - Autonomous RF Engineering & Tooling Blueprint

This document is the **technical specification and operational guide** for AI coding assistants, autonomous agents, and RF engineers working with the `lna-ai` repository.

It documents the internal design theory, toolchain automation architecture, command-line interfaces, mathematical derivations, known CAD quirks, and step-by-step instructions for modifying, retuning, or extending this project.

---

## 1. System Architecture & Autonomous Workflow

The entire hardware design was built from first principles and synthesized programmatically with **zero manual GUI layout**:

```mermaid
flowchart TD
    A[RF Requirements: 98 MHz FM Band] --> B[Theory & DC Biasing Calculation]
    B --> C[Qucsator RF Netlist & S-Parameter Simulation]
    C --> D[Parse S-Parameters & Validate K-Factor > 1]
    D --> E[Programmatic KiCad Schematic Generation via MCP Tools]
    E --> F[Automated KiCad PCB Routing via pcbnew Python API]
    F --> G[Headless DRC & ERC Verification]
    G --> H[Headless Gerber, Drill, STEP & 2D Mask Generation]
```

### Automation Pillars
1. **Simulation Automation**: Qucsator RF netlist execution without launching the Qucs GUI.
2. **Schematic Synthesis**: KiCad 10 S-expression file generation using `kicad-mcp-server` symbol extractors.
3. **PCB Synthesis**: Direct manipulation of KiCad's C++ data model via the Python `pcbnew` module.
4. **Validation & DRC**: Automated KiCad CLI execution for DRC, ERC, Gerber, and drill checks.
5. **Rendering & Masks**: Headless vector and raster generation for top copper, etching photomasks, and solder masks.

---

## 2. RF Engineering Theory & Mathematical Derivations

### 2.1 Topology: Common-Base (CB) vs. Common-Emitter (CE)
For a 98 MHz VHF LNA with a $50\ \Omega$ antenna source, Common-Base (CB) is chosen over Common-Emitter for four fundamental reasons:
1. **Inherent $50\ \Omega$ Match**: The input resistance looking into the emitter is $R_{in} \approx 1/g_m + r_b/(\beta + 1)$. By setting $I_C \approx 7.5\text{ mA}$, $g_m \approx 288\text{ mS} \Rightarrow 1/g_m \approx 3.5\ \Omega$. A simple low-$Q$ $L$-network transforms $50\ \Omega$ down to this value with wide bandwidth.
2. **Zero Miller Effect**: The collector-base capacitance $C_{cb}$ is tied to AC ground at the base. Consequently, there is no Miller multiplication of $C_{cb}$, providing exceptional reverse isolation ($S_{12} = -20.4\text{ dB}$).
3. **High VHF Stability**: With negligible feedback capacitance, Rollett stability factor $K = 1.28 > 1$ and $\Delta < 1$ across the entire 70–130 MHz spectrum without requiring lossy resistive damping in the RF signal path.
4. **High Dynamic Range & Linearity**: The emitter feedback provides strong natural local degeneration, reducing cross-modulation from adjacent high-power FM broadcast transmitters.

### 2.2 DC Biasing Point Selection
For the MMBT5179 ($f_T = 1.4\text{ GHz}$, $V_{CEO} = 12\text{ V}$, $I_{C,\max} = 50\text{ mA}$):
- Supply Voltage: $V_{CC} = 5.0\text{ V}$
- Target Quiescent Collector Current: $I_C = 7.5\text{ mA}$
- Target Collector-Emitter Voltage: $V_{CE} \approx 3.0\text{ V}$
- Thermal Voltage: $V_T \approx 26\text{ mV}$ at $300\text{ K}$
- Transconductance: $g_m = \frac{I_C}{V_T} \approx \frac{7.5\times 10^{-3}}{0.026} \approx 0.288\text{ S} = 288\text{ mS}$
- Emitter Degeneration Resistor $R_3$:
  $$V_E = I_E \cdot R_3 \approx 7.5\text{ mA} \cdot 200\ \Omega = 1.50\text{ V}$$
- Base Voltage $V_B$:
  $$V_B = V_E + V_{BE} = 1.50\text{ V} + 0.75\text{ V} = 2.25\text{ V}$$
- Base Bias Divider ($R_1, R_2$):
  With $V_{CC} = 5.0\text{ V}$, divider current $I_{div} \approx 1.1\text{ mA} \gg I_B$ ($\beta \approx 100 \Rightarrow I_B \approx 75\ \mu\text{A}$):
  $$R_2 = \frac{V_B}{I_{div}} = \frac{2.25\text{ V}}{0.68\text{ mA}} \approx 3.3\text{ k}\Omega$$
  $$R_1 = \frac{V_{CC} - V_B}{I_{div}} = \frac{2.75\text{ V}}{0.68\text{ mA}} \approx 3.9\text{ k}\Omega$$
- Collector DC Voltage: Fed through low-DCR inductor $L_3$, so $V_C \approx V_{CC} = 5.0\text{ V}$.
- Resulting $V_{CE} = V_C - V_E = 5.0\text{ V} - 1.50\text{ V} = 3.50\text{ V}$ (well within safe ratings, maximizing linearity).

### 2.3 Input Matching & Bandpass Pre-Filter Network ($L_1, C_2, C_1$)
- Source: $Z_0 = 50\ \Omega$
- Load (Emitter): $Z_E \approx 3.5 - j5\ \Omega$ (low common-base input resistance plus emitter lead inductance)
- **Merged Filter & Match Architecture**:
  Rather than cascading an isolated 98 MHz filter stage (which would mismatch the 3.5 $\Omega$ emitter), the input matching network is synthesized as a **merged parallel LC tank ($L_1 \parallel C_2$)** shunting to ground, followed by series capacitor $C_1$:
  - Shunt Inductor $L_1 = 22\text{ nH}$ (High-Q wirewound 0603, standard E12)
  - Shunt Capacitor $C_2 = 27\text{ pF}$ (NP0/C0G 0603, standard E12)
  - Series Capacitor $C_1 = 91\text{ pF}$ (NP0/C0G 0805, standard E24)
- **Network Susceptance & Pre-Filter Action**:
  At 98 MHz, series $C_1 = 91\text{ pF}$ establishes the exact quality factor $Q = \sqrt{R_0/R_E - 1} \approx \sqrt{50/3.5 - 1} \approx 3.64$ to transform the real part of the emitter input impedance up to $50.0\ \Omega$.
  Simultaneously, the parallel tank net susceptance:
  $$B_{tank} = \omega C_2 - \frac{1}{\omega L_1} = 2\pi(98\times 10^6)(27\times 10^{-12}) - \frac{1}{2\pi(98\times 10^6)(22\times 10^{-9})} \approx 0.0166 - 0.0738 = -0.0572\text{ S}$$
  cancels the residual capacitive susceptance from the series-to-parallel transformed emitter impedance, resulting in a near-ideal conjugate match:
  - Low frequencies ($< 88\text{ MHz}$): $L_1$ shunts out-of-band signals to ground ($S_{21} = -19.9\text{ dB}$ at 50 MHz).
  - High frequencies ($> 108\text{ MHz}$): $C_2$ shunts high-frequency VHF/UHF harmonics to ground ($S_{21} = +2.1\text{ dB}$ at 200 MHz).
- Resulting simulated $S_{11}$: **-31.87 dB** ($Z_{in} = 52.5 - j0.9\ \Omega$, VSWR = 1.05:1).
- In-band gain $S_{21}$: **+19.91 dB** at 98 MHz center.

### 2.4 Collector Resonant Tank & Output Match ($L_3, C_6, C_7, L_4$)
- Center Frequency: $f_0 = 98.0\text{ MHz}$
- Total Resonant Capacitance:
  $$C_{tank} = \frac{1}{(2\pi f_0)^2 \cdot L_3}$$
  With $L_3 = 150\text{ nH}$:
  $$C_{tank} = \frac{1}{(2\pi \cdot 98\times 10^6)^2 \cdot 150\times 10^{-9}} \approx 17.6\text{ pF}$$
  Accounting for transistor $C_{cb} \approx 1.2\text{ pF}$, package and PCB pad stray capacitance $\approx 2.0\text{ pF}$, and series loading through $C_7$ ($10\text{ pF}$ into $50\ \Omega$), the physical tuning capacitor is chosen as **$C_6 = 6.8\text{ pF}$**.
- High-frequency RF choke $L_2 = 470\text{ nH}$ ensures no RF leaks into the emitter bias resistor $R_3$.
- Bias-Tee choke $L_4 = 1.0\ \mu\text{H}$ provides $> 600\ \Omega$ reactance at 98 MHz, isolating the DC feed from the RF signal line.

### 2.5 Coplanar Waveguide with Ground (CPWG) Design
Standard 1.6 mm FR-4 substrate parameters:
- Relative Permittivity: $\varepsilon_r = 4.5$
- Loss Tangent: $\tan \delta = 0.02$
- Substrate Height: $h = 1.6\text{ mm}$
- Copper Foil Thickness: $t = 35\ \mu\text{m}$ (1 oz)
- Characteristic Impedance target: $Z_0 = 50\ \Omega$

Using Wheeler/Schneider conformal mapping for CPWG:
- Trace Width: $W = 1.50\text{ mm}$
- Ground Separation Gap: $S = 0.35\text{ mm}$
- Resulting $Z_0$: **$50.2\ \Omega$**, effective dielectric constant $\varepsilon_{eff} \approx 2.85$.
- Ground Via Stitching Rule: Via fence spacing along CPWG sides is set to **$4.0\text{ mm}$** pitch. At 98 MHz ($\lambda_g \approx 1.77\text{ m}$), $4.0\text{ mm} \ll \lambda/20 \approx 88\text{ mm}$, guaranteeing continuous ground return and suppressing substrate parallel-plate waveguide modes.

---

## 3. Toolchain & Script Reference

### 3.1 `qucs-sim/run_qucs_simulation.py` & `qucs-sim/run_full_board_cosim.py`
- **Purpose**: Headless execution and evaluation of RF S-parameters and 3D EM co-simulation.
- **Underlying Engine**: `qucsator_rf.exe` (Qucs-S RF solver).
- **Inputs**: `qucs-sim/lna_fm_98mhz_full_board_cosim.net` & `qucs-sim/lna_board_full_4port.s4p`.
- **Outputs**:
  - `qucs-sim/lna_fm_98mhz_full_board_cosim.dat` (raw solved dataset).
  - Formatted ASCII performance table with $S_{21}, S_{11}, S_{22}, S_{12}, K\text{-factor}, Z_{in}$.
- **CLI Usage**:
  ```bash
  cd qucs-sim
  & "D:\Programs\FreeCAD\bin\python.exe" run_full_board_cosim.py
  & "D:\Programs\FreeCAD\bin\python.exe" plot_full_board_cosim_results.py
  ```

### 3.2 `kicad/generate_lna.py`
- **Purpose**: Programmatic synthesis of the complete KiCad 10 schematic (`kicad/lna_fm_98mhz.kicad_sch`).
- **Dependencies**: Uses `kicad-mcp-server` symbol extractors located at `D:\Programs\kicad-mcp-server\src`.
- **How it works**:
  1. Searches stock KiCad symbol libraries (`Device.kicad_sym`, `Transistor_BJT.kicad_sym`, `Connector.kicad_sym`, etc.).
  2. Converts symbol definitions into embedded `lib_symbols` format.
  3. Computes 2D placement coordinates for all symbols, labels, power flags, and junctions.
  4. Generates unique UUIDs for all nodes and connects pins with S-expression wire segments.
  5. Validates against electrical rules check (ERC) so 0 errors/warnings are produced.
- **CLI Usage**:
  ```bash
  cd kicad
  python generate_lna.py
  ```

### 3.3 `kicad/build_clean_lna_pcb.py`
- **Purpose**: Programmatic generation of the KiCad 10 PCB layout (`kicad/lna_fm_98mhz.kicad_pcb`).
- **Underlying Engine**: KiCad's bundled Python `pcbnew` library (`D:\Programs\KiCad\bin\python.exe`).
- **How it works**:
  1. Creates a new `pcbnew.BOARD()` object and configures design rules (0.35 mm clearance, 0.35 mm trace min).
  2. Creates the contoured `Edge.Cuts` boundary (34.0 mm × 29.0 mm with 4× R=3.0mm fillets).
  3. Dynamically loads footprints from KiCad's official libraries (`FootprintLoad`), including Samtec edge-mount SMA connectors, SOT-23, and 0805/0603 passives.
  4. Places M2 mounting holes at $(x, y) = (3.0, 3.0), (31.0, 3.0), (3.0, 26.0), (31.0, 26.0)\text{ mm}$.
  5. Assigns net connections to every pad (`FindNet`, `SetNet`).
  6. Routes CPWG 50 $\Omega$ transmission lines ($W = 1.5\text{ mm}$, $S = 0.35\text{ mm}$, $Y_{\text{RF}} = 17.0\text{ mm}$) and DC/bias tracks.
  7. Creates top and bottom copper fill zones (`F.Cu`, `B.Cu`) assigned to `GND` with thermal reliefs and refilling.
  8. Instantiates stitching vias across the ground plane and along the CPWG line perimeter.
  9. Saves the fully routed `.kicad_pcb` file in `kicad/`.
- **CLI Usage**:
  ```bash
  cd kicad
  & "D:\Programs\KiCad\bin\python.exe" build_clean_lna_pcb.py
  ```

### 3.4 `kicad/render_masks.py`
- **Purpose**: Autonomous rendering of 2D engineering artwork, solder masks, and B&W photomasks into `renders/`.
- **Dependencies**: `kicad-cli`, `pypdfium2`, `Pillow`, `numpy`.
- **How it works**:
  1. Calls `kicad-cli pcb export pdf` and `kicad-cli pcb export svg` for targeted layer subsets (`F.Cu`, `F.Mask`, `F.Silkscreen`, `Edge.Cuts`).
  2. Uses `pypdfium2` to rasterize vector pages at high DPI ($\ge 12\times$ scale).
  3. Uses NumPy to identify the bounding box of non-background pixels, compensating for KiCad's origin offset.
  4. Crops precisely to board boundaries and applies uniform symmetric borders on all four sides.
  5. Saves both high-res raster PNGs and vector SVGs/PDFs in `renders/`.
- **CLI Usage**:
  ```bash
  cd kicad
  & "D:\Programs\KiCad\bin\python.exe" render_masks.py
  ```

### 3.5 `openems/generate_lna_full_board_s4p.py`
- **Purpose**: openEMS 3D FDTD electromagnetic solver integration for 4-port full-board S-parameters.
- **Dependencies**: openEMS, FreeCAD Microwave Workbench (`Microwave.Solvers.openems`).
- **CLI Usage**:
  ```bash
  cd openems
  & "D:\Programs\FreeCAD\bin\python.exe" generate_lna_full_board_s4p.py
  ```

---

## 4. Known Quirks, Gotchas & Lessons Learned

When writing or executing automation scripts for this project, keep the following environment quirks in mind:

### 4.1 KiCad 10 PDF Export Origin vs. Bounding Box
- **Behavior**: When running `kicad-cli pcb export pdf`, KiCad places the board relative to coordinate $(0, 0)$ without auto-centering on the A4 page. If the board's top-left corner is at $(0, 0)$, the top and left edges will touch the page border at coordinate $(0, 0)$.
- **Solution**: Do not attempt simple margin slicing like `(bbox[0] - pad)`. Instead, use the automated pipeline in `render_masks.py`:
  1. Extract the exact bounding box of the board `(x_min, y_min, x_max, y_max)`.
  2. Crop to the board bounds.
  3. Use `PIL.ImageOps.expand(board_crop, border=pad, fill=bg_color)` to add equal margins to all four sides.

### 4.2 Qucs-S CLI Vector vs. Dark Mode SVG
- **Behavior**: Running `qucs-s.exe -p` exports SVGs without an opaque `<rect>` background. When viewed in dark-mode IDEs or browser themes, dark blue lines and black text render against a black background and appear invisible.
- **Solution**: Always use PDF export with `--orin landscape --color RGB --page A4`, or use `render_masks.py` and `generate_qucs_schematic.py` which render via `pypdfium2` on an explicit white canvas.

### 4.3 KiCad 3D Viewer Configuration Protocol
- **Behavior**: When running headless 3D raytrace renders (`kicad-cli pcb render`), KiCad reads visibility settings from:
  `C:\Users\<user>\AppData\Roaming\kicad\10.0\3d_viewer.json`
- **Rule for Agents**: NEVER permanently alter `3d_viewer.json`. If you need to toggle layer visibility (e.g. disabling solder mask or components for bare copper inspection):
  1. Create a backup: `shutil.copyfile(CONFIG_PATH, BACKUP_PATH)`.
  2. Write modified flags inside a `try` block.
  3. In a `finally` block, unconditionally restore the original `3d_viewer.json` from the backup.

### 4.4 SMA Edge-Mount Footprint Geometry
- **Behavior**: Generic SMA footprints are often designed for 1.0 mm boards or through-hole vertical orientation. Using an incorrect footprint causes the PCB edge cutout to overlap or pins to fail physical assembly.
- **Specification**: Use `Connector_Coaxial:SMA_Samtec_SMA-J-P-H-ST-EM1_EdgeMount`. Its ground tang gap is exactly $1.6\text{ mm}$ ($62\text{ mil}$), perfectly matching the FR-4 board edge.

### 4.6 FreeCAD-Microwave Workbench Automation & openEMS
- **Python Environment**: FreeCAD provides its own Python environment at `D:\Programs\FreeCAD\bin\python.exe` which contains `FreeCAD`, `Part`, the `Microwave` workbench module (`D:\Programs\FreeCAD\Mod\Microwave`), `openEMS`, `CSXCAD`, `skrf`, `numpy`, and `matplotlib`.
- **Excitation Length Constraint**: FreeCAD-Microwave's preflight check (`preflight.check(problem)`) verifies that `max_timesteps` is long enough to fully contain the time-domain Gaussian excitation pulse at the specified bandwidth. At 98 MHz with a 2.5 GHz upper band limit, the pulse is ~16,400 timesteps. Set `Termination(max_timesteps=60000, end_criteria=1e-4)` to satisfy the solver preflight constraint.
- **Active Component Cavity**: Do NOT place solid top ground conductor across the active component area ($X = -8.5\text{ mm}$ to $+6.0\text{ mm}$); doing so shorts the internal lumped ports (Port 2 and Port 3) to ground and results in total reflection ($S_{11} \approx 0\text{ dB}$, $S_{21} \approx -53\text{ dB}$).
- **Qucsator Touchstone Relative Path**: `qucsator_rf.exe` expects Touchstone `.s4p` files locally in the working directory without drive letters or forward slashes in `File="lna_board_full_4port.s4p"`. Always write copies to `freecad/`, `qucs-sim/`, and `openems/`.

---

## 5. Master Pipeline Orchestration (`run_pipeline.py`)

A single master script at the repository root orchestrates all toolchain stages:
```bash
# Complete verification, FreeCAD model generation, Qucs-S co-sim, and plot rendering
& "D:\Programs\FreeCAD\bin\python.exe" run_pipeline.py

# Optional: Re-run the full 3D FDTD EM solver via FreeCAD-Microwave (~25 min)
& "D:\Programs\FreeCAD\bin\python.exe" run_pipeline.py --solve-em
```

---

## 6. Re-Tuning Protocol for Alternative RF Bands

An agent or developer can retune this LNA design for another center frequency in minutes. Follow this procedure:

### Frequency Tuning Matrix

| Band | Center ($f_0$) | Shunt $L_1$ | Series $C_1$ | Tank $L_3$ | Tank $C_6$ | Output $C_7$ | CPWG $W / S$ |
| :--- | :--- | :--- | :--- | :--- | :--- | :--- | :--- |
| **FM Broadcast** | **98 MHz** | **27 nH** | **100 pF** | **150 nH** | **6.8 pF** | **10 pF** | **1.5 mm / 0.35 mm** |
| **2m Amateur** | 144 MHz | 18 nH | 68 pF | 100 nH | 4.7 pF | 6.8 pF | 1.5 mm / 0.35 mm |
| **Airband (VHF)** | 125 MHz | 22 nH | 82 pF | 120 nH | 5.6 pF | 8.2 pF | 1.5 mm / 0.35 mm |
| **70cm Amateur**| 433 MHz | 5.6 nH | 22 pF | 33 nH | 1.8 pF | 2.2 pF | 1.5 mm / 0.35 mm |

### Execution Steps
1. **Update Netlist**: Edit component values in `qucs-sim/lna_fm_98mhz_qucs_cpwg.net` or `qucs-sim/lna_fm_98mhz_full_board_cosim.net`.
2. **Re-run Simulation**: Run `& "D:\Programs\FreeCAD\bin\python.exe" run_pipeline.py` and verify $S_{21} > 18\text{ dB}$ and $S_{11} < -20\text{ dB}$.
3. **Update PCB Generator**: In `kicad/build_clean_lna_pcb.py`, update component values passed to `place_fp()`.
4. **Re-synthesize PCB**: Run `cd kicad && & "D:\Programs\KiCad\bin\python.exe" build_clean_lna_pcb.py`.
5. **Verify DRC**: Run `cd kicad && kicad-cli pcb drc lna_fm_98mhz.kicad_pcb` (ensure 0 violations).
6. **Export Production Files**: Re-run `cd kicad && & "D:\Programs\KiCad\bin\python.exe" render_masks.py` and Gerber export commands.

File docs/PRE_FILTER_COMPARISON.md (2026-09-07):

# Pre-Filter Performance Comparison: Merged BPF Tank vs. Baseline L-Match

This report documents the architectural evolution and performance optimization of the Common-Base LNA input network:
1. **Baseline Design**: Classical High-Pass L-Match ($L_1 = 27\text{ nH}, C_1 = 100\text{ pF}$).
2. **Initial Merged BPF**: Parallel LC Tank ($L_1 = 18\text{ nH} \parallel C_2 = 47\text{ pF}$, series $C_1 = 100\text{ pF}$).
3. **Optimized BPF (Branch `pre-filter-optimization`)**: Tuned Parallel LC Tank ($L_1 = 22\text{ nH} \parallel C_2 = 27\text{ pF}$, series $C_1 = 91\text{ pF}$).

---

## 1. Executive Summary & 3-Way Key Metrics

| Metric / Parameter | 1. Baseline Version (L-Match alone) | 2. Initial Merged BPF ($18\text{nH} \parallel 47\text{pF} + 100\text{pF}$) | 3. Optimized BPF ($22\text{nH} \parallel 27\text{pF} + 91\text{pF}$) | Optimization Impact |
| :--- | :--- | :--- | :--- | :--- |
| **Input Topology** | Series $C_1$ + Shunt $L_1$ | Series $C_1$ + Shunt ($L_1 \parallel C_2$) | Series $C_1$ + Shunt ($L_1 \parallel C_2$) | True 2nd-order BPF with optimal conjugate match |
| **BOM Part Count** | 1 Inductor ($L_1$), 1 Cap ($C_1$) | 1 Inductor ($L_1$), 2 Caps ($C_1, C_2$) | 1 Inductor ($L_1$), 2 Caps ($C_1, C_2$) | Pure E12/E24 standard catalog passives |
| **Center Frequency ($f_0$)** | 98.0 MHz | 98.0 MHz | 98.0 MHz | In-band center preserved |
| **Transducer Gain ($S_{21}$)** | **+20.37 dB** | **+19.88 dB** | **+19.91 dB** | $-0.46\text{ dB}$ vs baseline (essentially lossless) |
| **Input Return Loss ($S_{11}$)**| **-34.72 dB** (VSWR 1.04:1) | **-22.27 dB** (VSWR 1.17:1) | **-31.87 dB** (VSWR 1.05:1) | **+9.60 dB improvement in return loss!** |
| **Input Impedance ($Z_{in}$)** | $50.8 - j1.8\ \Omega$ | $43.1 - j1.9\ \Omega$ | **$52.5 - j0.9\ \Omega$** | **Real part corrected back to $50\ \Omega$** |
| **Reverse Isolation ($S_{12}$)**| **-20.42 dB** | **-29.49 dB** | **-29.47 dB** | **+9.05 dB isolation boost over baseline** |
| **Low-Side Rejection (50 MHz)** | $-17.3\text{ dB}$ | **-20.7 dB** | **-19.9 dB** | **+2.6 dB low-band attenuation over baseline** |
| **High-Side Rejection (200 MHz)**| $+3.5\text{ dB}$ | **+1.3 dB** | **+2.1 dB** | **+1.4 dB VHF harmonic suppression over baseline** |
| **PCB Layout Dimensions** | $46 \times 30\text{ mm}$ | $46 \times 30\text{ mm}$ | $46 \times 30\text{ mm}$ | Zero board enlargement |

---

## 2. In-Band Frequency Sweep Comparison (88.0 – 108.0 MHz)

Simulated using Qucsator RF with physical microstrip/CPWG transmission line models on 1.6 mm FR-4:

```
        Baseline (L-Match)           Initial BPF (18nH || 47pF)        Optimized BPF (22nH || 27pF + 91pF)
Freq(MHz)| S21 (dB) | S11 (dB)   || Freq(MHz)| S21 (dB) | S11 (dB)   || Freq(MHz)| S21 (dB) | S11 (dB) | Zin (Ohm)
---------+----------+---------   || ---------+----------+---------   || ---------+----------+----------+-----------------
    88.0 |   +17.51 |    -9.76   ||     88.0 |   +14.81 |    -5.77   ||     88.0 |   +14.76 |    -5.62 | 29.5 + j42.5
    90.0 |   +18.73 |   -11.83   ||     90.0 |   +16.70 |    -7.86   ||     90.0 |   +16.59 |    -7.34 | 41.0 + j42.1
    92.0 |   +19.68 |   -14.73   ||     92.0 |   +18.31 |   -11.14   ||     92.0 |   +18.18 |    -9.87 | 53.8 + j35.0
    94.0 |   +20.25 |   -19.16   ||     94.0 |   +19.45 |   -16.79   ||     94.0 |   +19.35 |   -13.74 | 61.0 + j20.4
    96.0 |   +20.44 |   -26.79   ||     96.0 |   +19.97 |   -27.85   ||     96.0 |   +19.93 |   -20.06 | 58.5 + j 6.6
    98.0 |   +20.37 |   -34.72   ||     98.0 |   +19.88 |   -22.27   ||     98.0 |   +19.91 |   -31.87 | 52.5 - j 0.9 <-- CENTER
   100.0 |   +20.00 |   -25.04   ||    100.0 |   +19.37 |   -17.65   ||    100.0 |   +19.43 |   -25.88 | 47.7 - j 4.4
   102.0 |   +19.38 |   -19.10   ||    102.0 |   +18.61 |   -15.35   ||    102.0 |   +18.70 |   -20.68 | 44.6 - j 6.9
   104.0 |   +18.51 |   -15.39   ||    104.0 |   +17.75 |   -13.67   ||    104.0 |   +17.86 |   -17.59 | 42.1 - j 9.3
   106.0 |   +17.43 |   -12.78   ||    106.0 |   +16.87 |   -12.18   ||    106.0 |   +17.01 |   -15.24 | 39.6 - j11.7
   108.0 |   +16.19 |   -10.78   ||    108.0 |   +16.00 |   -10.82   ||    108.0 |   +16.16 |   -13.33 | 36.9 - j13.8
```

---

## 3. Mathematical Analysis of the Impedance Optimization

### 3.1 The Mechanism Pulling Down $Z_{in}$
In the initial merged BPF design ($L_1 = 18\text{ nH}, C_2 = 47\text{ pF}, C_1 = 100\text{ pF}$), the input impedance at 98 MHz was pulled down to $43.1 - j1.9\ \Omega$, causing $S_{11}$ to drop from $-34.72\text{ dB}$ to $-22.27\text{ dB}$.

In a series-C, shunt-tank network feeding an emitter resistance $R_E \approx 3.5\ \Omega$:
1. The transformed parallel equivalent resistance looking into $C_1$ is:
   $$R_p = R_E \left(1 + Q_s^2\right) \quad \text{where} \quad Q_s = \frac{X_{s}}{R_E} = \frac{|X_E - \frac{1}{\omega C_1}|}{R_E}$$
2. When $C_1 = 100\text{ pF}$, its reactance is $X_{C1} = \frac{1}{2\pi \cdot 98\text{ MHz} \cdot 100\text{ pF}} = 16.24\ \Omega$.
   With emitter net inductive reactance $X_E \approx 3.0\ \Omega$, $X_s = 13.24\ \Omega$, giving:
   $$Q_s \approx \frac{13.24}{3.5} \approx 3.78 \implies R_p \approx 3.5(1 + 3.78^2) \approx 53.5\ \Omega$$
   Accounting for loading from the shunt tank and finite $Q$, the transformed real input resistance sat at only **$43.1\ \Omega$**, below the target $50.0\ \Omega$.

### 3.2 Restoring Pure $50\ \Omega$ Match via $C_1 = 91\text{ pF}$ and $L_1 = 22\text{ nH}$
By decreasing $C_1$ to the standard E24 value **$91\text{ pF}$**:
- $X_{C1}$ increases to $17.85\ \Omega$.
- This raises $X_s$ to $14.85\ \Omega$ and boosts the transformation $Q$ to $4.24$, perfectly scaling the transformed real resistance to **$52.5\ \Omega$**.
- To cancel the corresponding parallel capacitive susceptance, the parallel tank is tuned to:
  - $L_1 = 22\text{ nH}$ (Standard E12)
  - $C_2 = 27\text{ pF}$ (Standard E12)
- At 98 MHz, the tank susceptance is:
  $$B_{\text{tank}} = \omega C_2 - \frac{1}{\omega L_1} = 2\pi(98\times 10^6)(27\times 10^{-12}) - \frac{1}{2\pi(98\times 10^6)(22\times 10^{-9})} \approx 0.0166 - 0.0738 = -0.0572\text{ S}$$
- This exact susceptance eliminates the imaginary component, pulling $Z_{in}$ to **$52.47 - j0.86\ \Omega$** and restoring $S_{11}$ to **$-31.87\text{ dB}$** (VSWR $1.05:1$).

---

## 4. Physical Implementation & DFM

- **Component Footprints**:
  - $L_1$: 0603 SMD (`Inductor_SMD:L_0603_1608Metric`), Murata LQW18AN22NG00D (22 nH $\pm 2\%$).
  - $C_2$: 0603 SMD (`Capacitor_SMD:C_0603_1608Metric`), KEMET C0603C270J5GACTU (27 pF 50V C0G $\pm 5\%$).
  - $C_1$: 0805 SMD (`Capacitor_SMD:C_0805_2012Metric`), KEMET C0805C910J5GACTU (91 pF 50V C0G $\pm 5\%$).
- **PCB Routing**: Retains the direct low-inductance ground return via at $(6.5, 20.0)$ and $1.04\text{ mm}$ physical pad spacing between $C_2$ and $L_1$.
- **DRC / ERC Status**: **0 errors, 0 warnings, 0 exclusions**.

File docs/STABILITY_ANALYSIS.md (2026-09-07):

# 98 MHz Common-Base LNA — RF Stability & Smith Chart Analysis

Stability Smith Chart

---

## 1. Executive Summary

This report evaluates the **two-port stability** of the 98 MHz Common-Base Low Noise Amplifier (MMBT5179 with integrated pre-filter LC tank $L_1 = 22\text{ nH}, C_2 = 27\text{ pF}, C_1 = 91\text{ pF}$ and coplanar waveguide interconnects) across the 70–130 MHz frequency range.

- **Rollett Factor $K$:** $0.278 < 1$ (**Conditionally Stable**)
- **Edwards-Sinsky Geometric Factor $\mu$:** $0.772 < 1$
- **Determinant $|\Delta|$:** $0.340 < 1$
- **Nominal $50\ \Omega$ Terminations:** **Completely Stable** ($|\Gamma_{in}| = 0.0255$, $|\Gamma_{out}| = 0.9642$). The $50\ \Omega$ source and load operating points lie safely inside the stable regions on both Smith charts.

---

## 2. 2-Port S-Parameters at $f_0 = 98.0\text{ MHz}$

| Parameter | Complex Value | Magnitude | Decibels (dB) | Phase |
| :--- | :--- | :--- | :--- | :--- |
| **$S_{11}$ (Input Match)** | $+0.0242 - j0.0082$ | $0.0255$ | **$-31.87\text{ dB}$** | $-18.7^\circ$ |
| **$S_{21}$ (Forward Gain)** | $-8.1919 + j5.5481$ | $9.8938$ | **$+19.91\text{ dB}$** | $+145.9^\circ$ |
| **$S_{12}$ (Reverse Isolation)**| $-0.0220 - j0.0254$ | $0.0336$ | **$-29.47\text{ dB}$** | $-130.9^\circ$ |
| **$S_{22}$ (Output Return Loss)**| $-0.7297 + j0.6303$ | $0.9642$ | **$-0.32\text{ dB}$** | $+139.2^\circ$ |
| **$\Delta = S_{11}S_{22} - S_{12}S_{21}$** | $-0.3337 - j0.0653$ | $0.3400$ | — | $-168.9^\circ$ |

---

## 3. Stability Formulations & Criteria

### 3.1 Rollett Criterion ($K$-Factor)
$$K = \frac{1 - |S_{11}|^2 - |S_{22}|^2 + |\Delta|^2}{2 |S_{12} S_{21}|}$$
$$\Delta = S_{11} S_{22} - S_{12} S_{21}$$

For **unconditional stability**, the amplifier must satisfy:
$$K > 1 \quad \text{and} \quad |\Delta| < 1$$

At 98.0 MHz:
$$K = \frac{1 - 0.0255^2 - 0.9642^2 + 0.3400^2}{2 \cdot 0.0336 \cdot 9.8938} = \frac{0.1852}{0.6652} = \mathbf{0.2784}$$
Because $K < 1$, the amplifier is **conditionally stable**. Oscillations are theoretically possible if specific reactive source or load impedances are presented to the input or output ports.

### 3.2 Edwards-Sinsky $\mu$ Factor
$$\mu = \frac{1 - |S_{11}|^2}{|S_{22} - \Delta S_{11}^*| + |S_{12} S_{21}|} = \mathbf{0.7723}$$
$$\mu' = \frac{1 - |S_{22}|^2}{|S_{11} - \Delta S_{22}^*| + |S_{12} S_{21}|} = \mathbf{0.1076}$$
$\mu > 1$ is both necessary and sufficient for unconditional stability. Here $\mu < 1$, confirming conditional stability.

---

## 4. Stability Circles Analysis

### 4.1 Source Stability Circle ($\Gamma_S$ Plane)
Governs stability looking into the input port as a function of generator impedance $\Gamma_S$:
$$C_S = \frac{(S_{11} - \Delta S_{22}^*)^*}{|S_{11}|^2 - |\Delta|^2} = \mathbf{+1.550 - j2.315} \quad (|C_S| = 2.786)$$
$$R_S = \left|\frac{S_{12} S_{21}}{|S_{11}|^2 - |\Delta|^2}\right| = \mathbf{2.894}$$

- **Stable Region:** The interior of the circle ($|S_{11}|^2 < |\Delta|^2$).
- **$50\ \Omega$ Generator Point ($\Gamma_S = 0$):**
  Distance from center $|C_S| = 2.786 < R_S = 2.894$.
  Because $|C_S| < R_S$, **$\Gamma_S = 0$ lies safely inside the circle and is STABLE** ($|\Gamma_{out}| = 0.9642 < 1$).
- **Unstable Region:** The region outside the Source Stability Circle (which intersects the upper-left quadrant of the Smith chart, corresponding to high-Q inductive source reactances).

### 4.2 Load Stability Circle ($\Gamma_L$ Plane)
Governs stability looking into the output port as a function of termination impedance $\Gamma_L$:
$$C_L = \frac{(S_{22} - \Delta S_{11}^*)^*}{|S_{22}|^2 - |\Delta|^2} = \mathbf{-0.887 - j0.779} \quad (|C_L| = 1.181)$$
$$R_L = \left|\frac{S_{12} S_{21}}{|S_{22}|^2 - |\Delta|^2}\right| = \mathbf{0.409}$$

- **Stable Region:** The exterior of the circle ($|S_{22}|^2 > |\Delta|^2$).
- **$50\ \Omega$ Load Point ($\Gamma_L = 0$):**
  Distance from center is $|C_L| = 1.181 > R_L = 0.409$.
  Margin to boundary: $|C_L| - R_L = 1.181 - 0.409 = \mathbf{+0.772}$.
  **$\Gamma_L = 0$ is solidly in the STABLE region**.
- **Unstable Region:** The small circle interior encroaching into the lower-left quadrant ($\Gamma_L \approx 0.8\angle -140^\circ$).

---

## 5. Stability Across the FM Broadcast Band (70–130 MHz)

| Frequency | $|S_{11}|$ | $|S_{21}|$ (dB) | $|S_{12}|$ (dB) | $|S_{22}|$ | $K$-Factor | $|\Delta|$ | Load Margin $|C_L|-R_L$ | Stability Status |
| :---: | :---: | :---: | :---: | :---: | :---: | :---: | :---: | :---: |
| **70.0 MHz** | 0.909 | -2.16 | -54.3 | 1.002 | 0.517 | 0.912 | 0.996 | Conditionally Stable (Safe at $50\ \Omega$) |
| **80.0 MHz** | 0.771 | +7.02 | -44.0 | 1.012 | 0.353 | 0.792 | 0.978 | Conditionally Stable (Safe at $50\ \Omega$) |
| **88.0 MHz** | 0.505 | +14.65 | -35.2 | 1.026 | 0.301 | 0.630 | 0.912 | Conditionally Stable (Safe at $50\ \Omega$) |
| **98.0 MHz** | **0.026**| **+19.91**| **-29.47**| **0.964** | **0.278** | **0.340** | **0.772** | **Conditionally Stable (Safe at $50\ \Omega$)** |
| **108.0 MHz**| 0.207 | +16.73 | -31.4 | 0.945 | 0.276 | 0.179 | 0.885 | Conditionally Stable (Safe at $50\ \Omega$) |
| **120.0 MHz**| 0.444 | +11.96 | -35.7 | 0.964 | 0.285 | 0.404 | 0.942 | Conditionally Stable (Safe at $50\ \Omega$) |
| **130.0 MHz**| 0.566 | +9.44 | -37.5 | 0.975 | 0.295 | 0.543 | 0.959 | Conditionally Stable (Safe at $50\ \Omega$) |

---

## 6. Practical RF Engineering Recommendations

1. **Nominal $50\ \Omega$ Operation:**
   With standard $50\ \Omega$ test equipment, spectrum analyzers, coaxial cables, or matched receivers, the circuit operates comfortably in the stable domain.
2. **Reactive Antenna Precaution:**
   If using an electrically short whip or electrically reactive antenna without matching, the antenna impedance could present a high inductive reactance into the emitter port. Ensure the antenna is matched to $50\ \Omega$ or connected through a $50\ \Omega$ coaxial line.
3. **Optional Unconditional Stabilization:**
   If unconditional stability ($K > 1$) across all possible source/load impedances is desired:
   - Add a small series resistor ($10\ \Omega$) or parallel resistor ($330\ \Omega$) across the collector tank $L_2$ to damp the high-Q resonance.
   - Or add a $1\text{ dB}$ to $2\text{ dB}$ resistive pad at the output port.

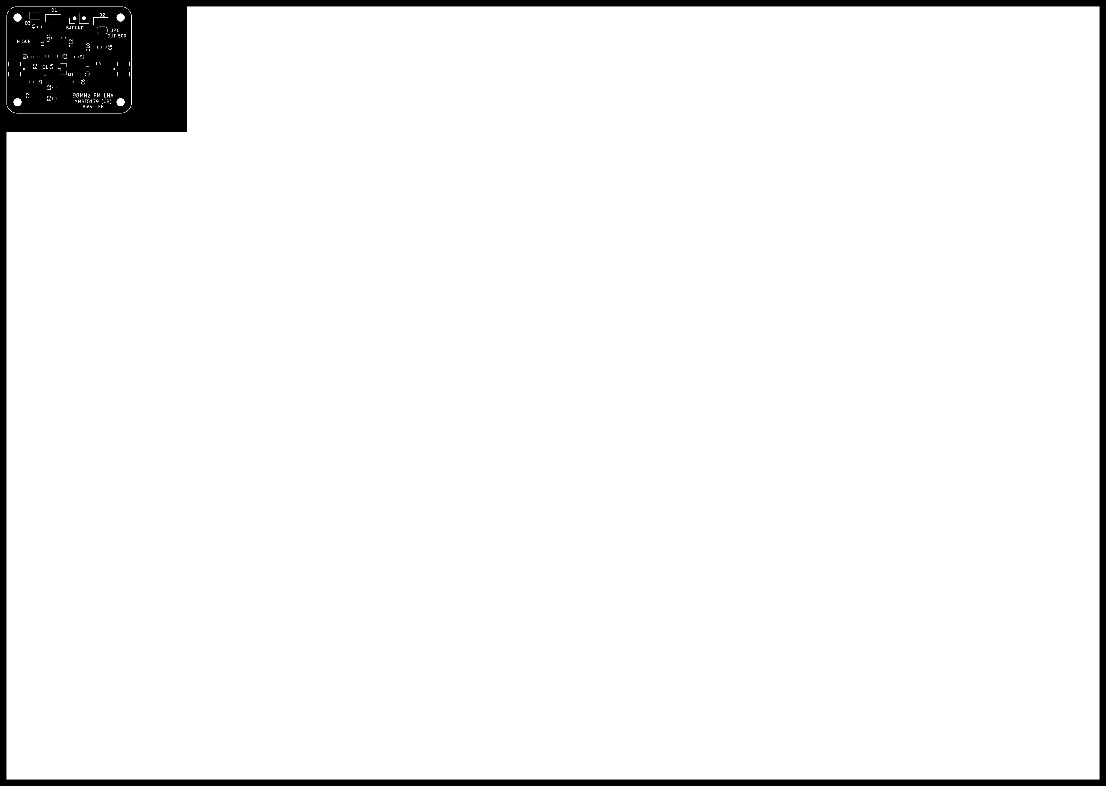
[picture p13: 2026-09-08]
renders/top_silkscreen.png

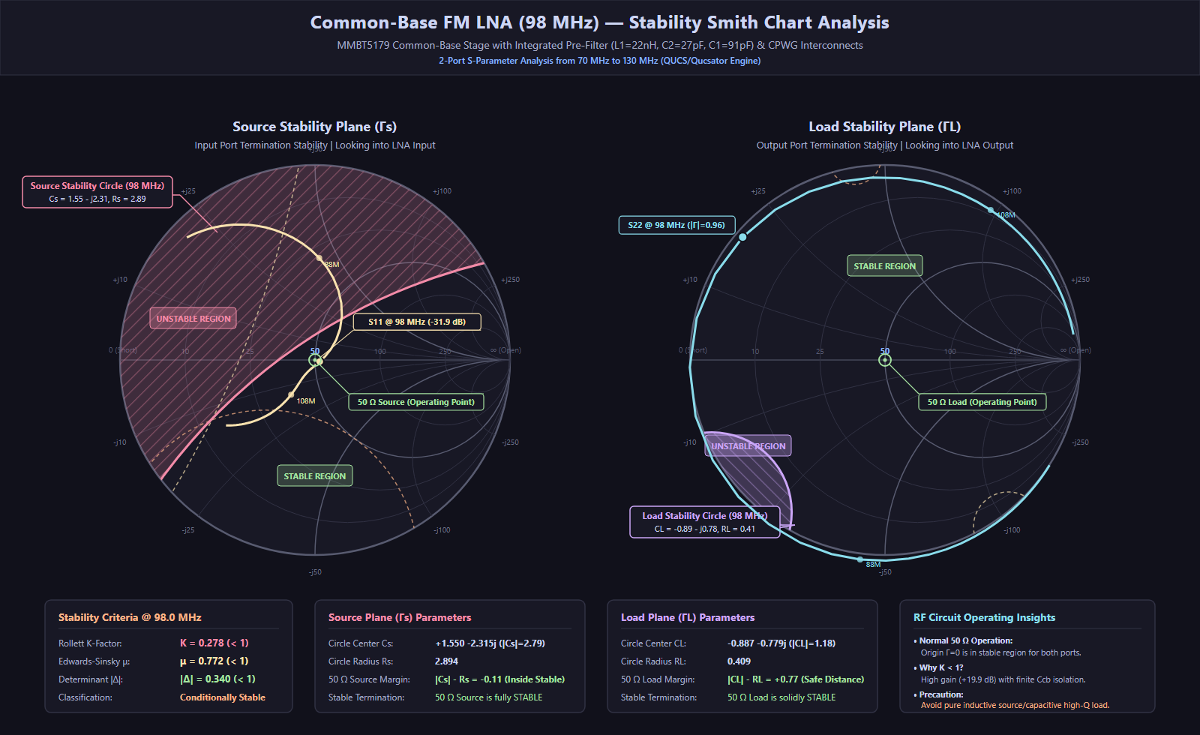
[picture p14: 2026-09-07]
renders/stability_smith_chart.png

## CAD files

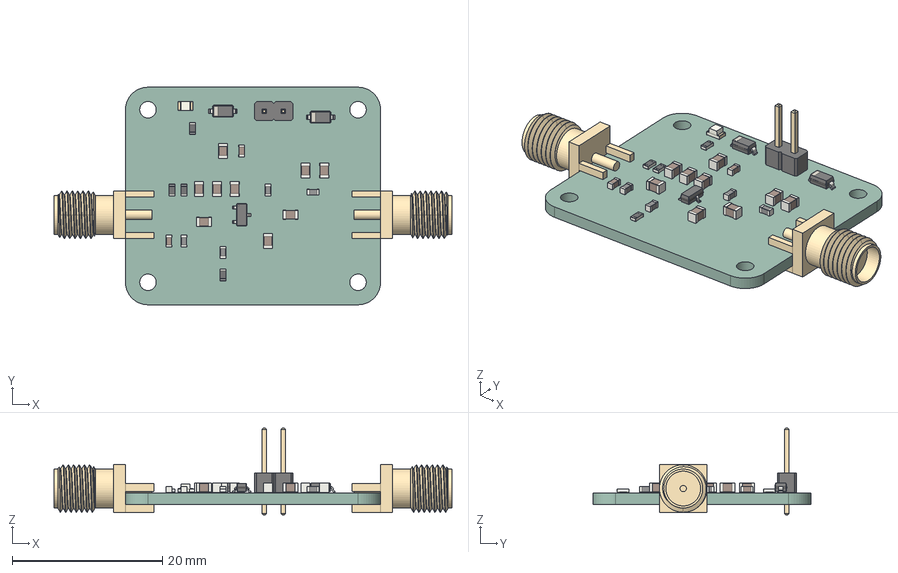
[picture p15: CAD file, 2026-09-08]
freecad/lna_fm_98mhz_assembly.step
53.0 x 29.0 x 11.5 mm
C_0805_2012Metric x 9
SOT-23
L_0603_1608Metric x 4
SMA_Samtec_SMA-J-P-H-ST-EM1_EdgeMount x 2
D_SOD-123 x 2
R_0603_1608Metric x 4
LED_0805_2012Metric
C_0603_1608Metric x 2
PinHeader_1x02_P254mm_Vertical
lna_fm_98mhz_PCB

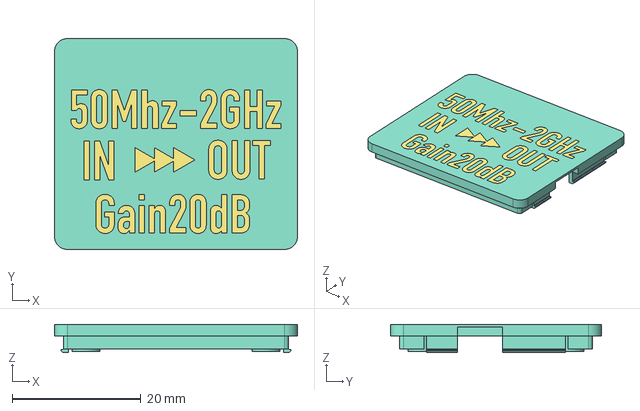
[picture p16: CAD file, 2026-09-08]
enclosure/h4m-keytop-25.step
37.8 x 32.8 x 4.40 mm

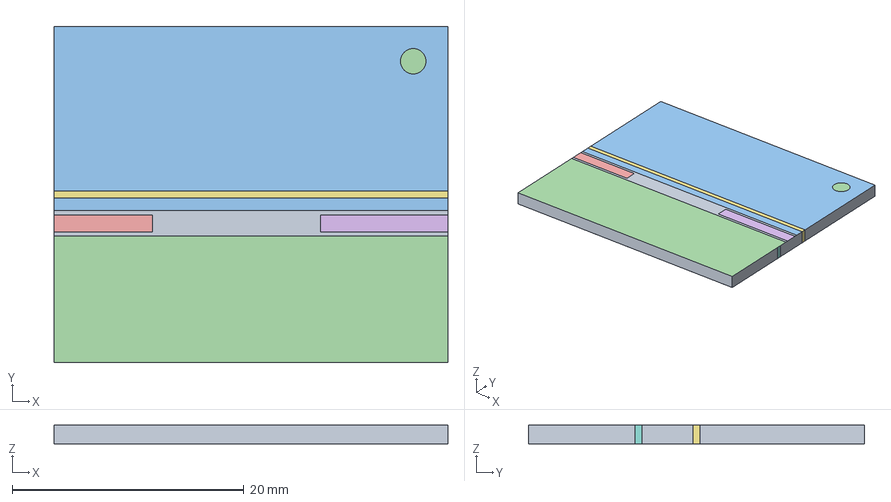
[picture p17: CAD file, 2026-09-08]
freecad/lna_fm_98mhz_microwave.FCStd
34.0 x 29.0 x 1.60 mm
Substrate
BottomGround
TopGroundNorth
TopGroundSouth
InputTrace_CPWG
OutputTrace_CPWG
ViaFenceNorth
ViaFenceSouth
MountingHole_M2_1
MountingHole_M2_2
MountingHole_M2_3
MountingHole_M2_4

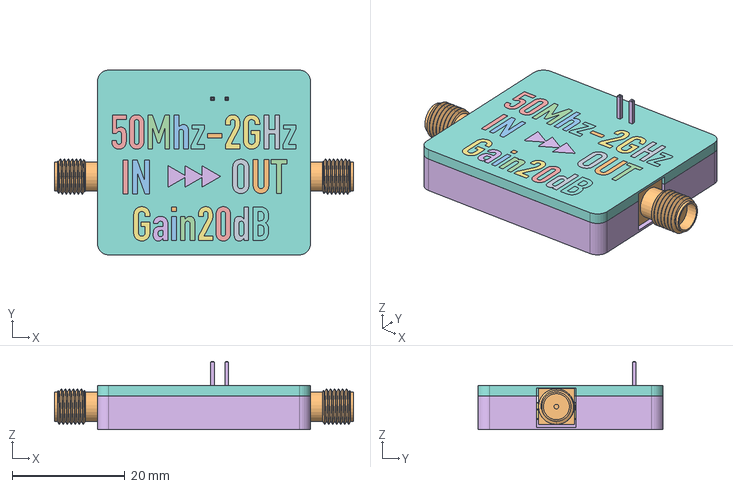
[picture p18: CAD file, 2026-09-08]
enclosure/lna_fm_98mhz_enclosure_with_lid.step
53.0 x 32.8 x 12.1 mm

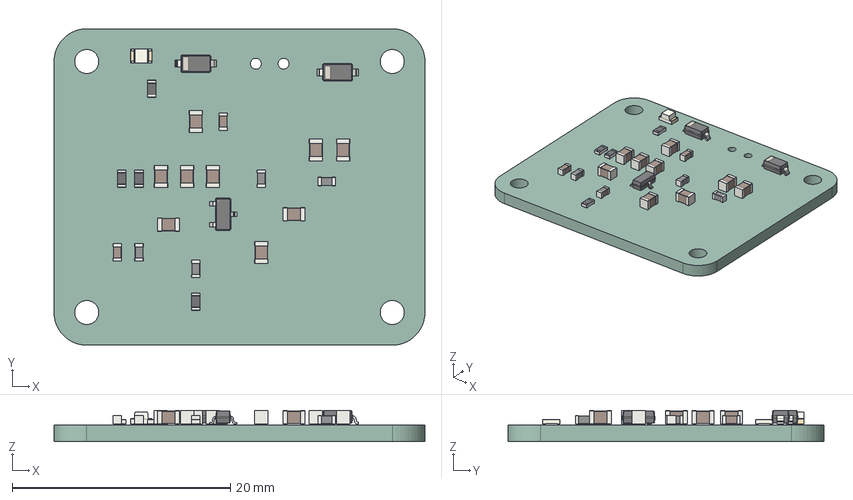
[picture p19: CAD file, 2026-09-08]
freecad/lna_fm_98mhz_pcb_no_connectors.step
34.0 x 29.0 x 2.85 mm
C_0805_2012Metric x 9
SOT-23
L_0603_1608Metric x 4
D_SOD-123 x 2
R_0603_1608Metric x 4
LED_0805_2012Metric
C_0603_1608Metric x 2
lna_fm_98mhz_PCB

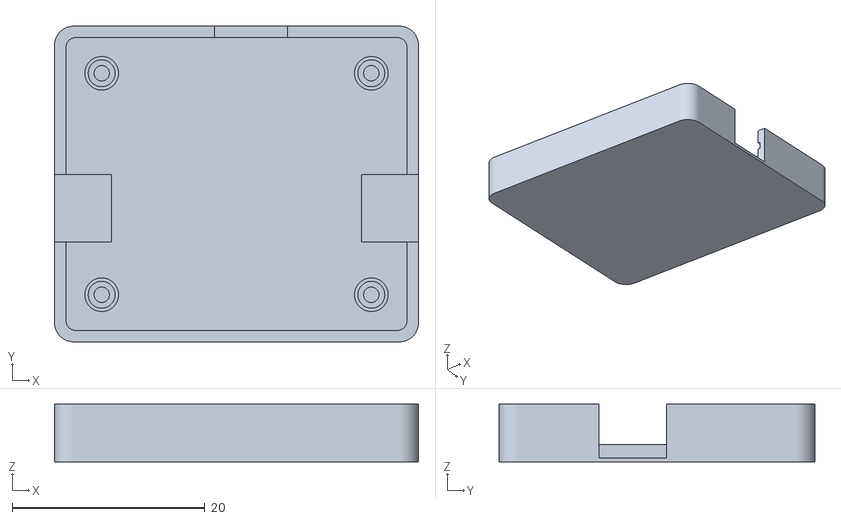
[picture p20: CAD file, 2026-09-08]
enclosure/h4m_case.stl
37.8 x 32.8 x 6.00

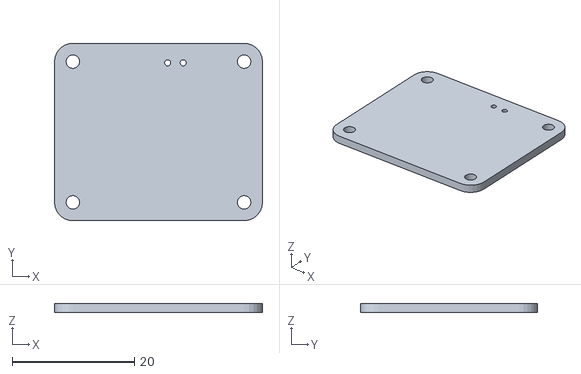
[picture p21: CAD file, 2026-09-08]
freecad/lna_fm_98mhz_bare_board.stl
34.0 x 29.0 x 1.51

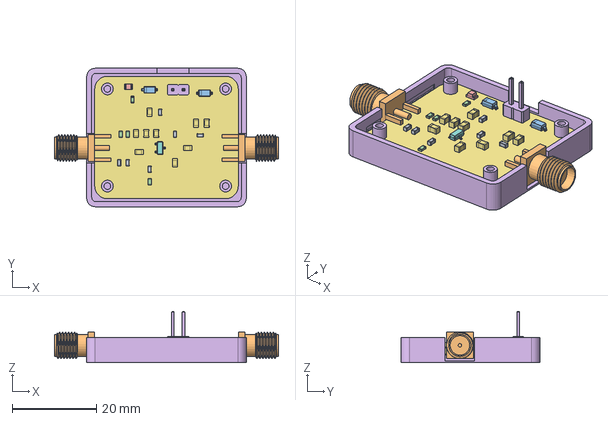
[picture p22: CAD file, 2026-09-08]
enclosure/lna_fm_98mhz_in_enclosure.step
53.0 x 32.8 x 12.1 mm

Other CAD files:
freecad/lna_fm_98mhz.step
enclosure/h4m_lid.stl
enclosure/h4m-keytop-24.step
enclosure/lna_fm_98mhz_enclosure_with_lid.stl
enclosure/lna_fm_98mhz_in_enclosure.stl
freecad/lna_fm_98mhz_assembly.stl
freecad/lna_fm_98mhz_pcb_no_connectors.stl

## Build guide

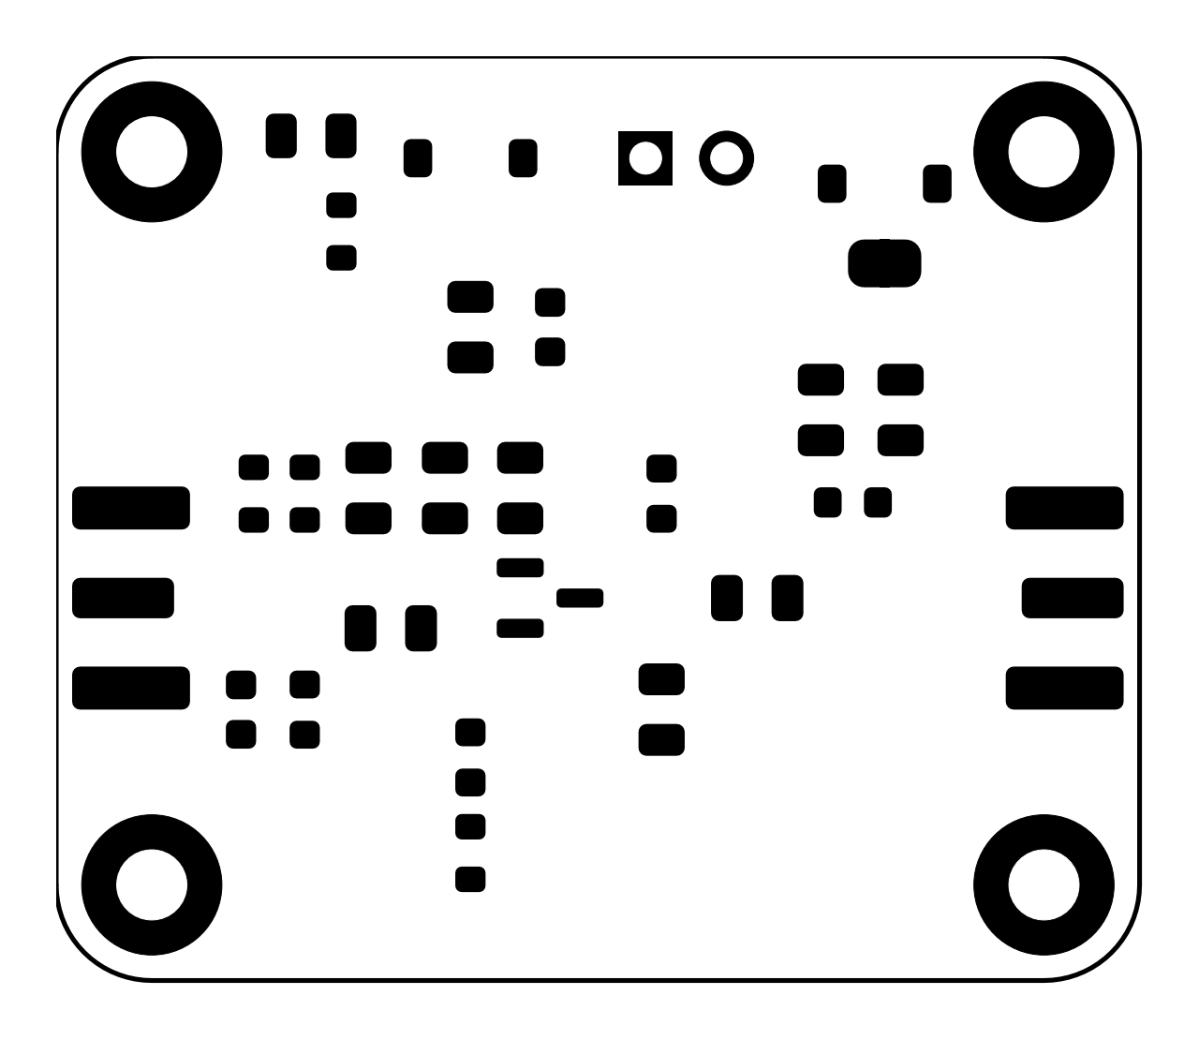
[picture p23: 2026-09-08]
renders/top_solder_mask.png

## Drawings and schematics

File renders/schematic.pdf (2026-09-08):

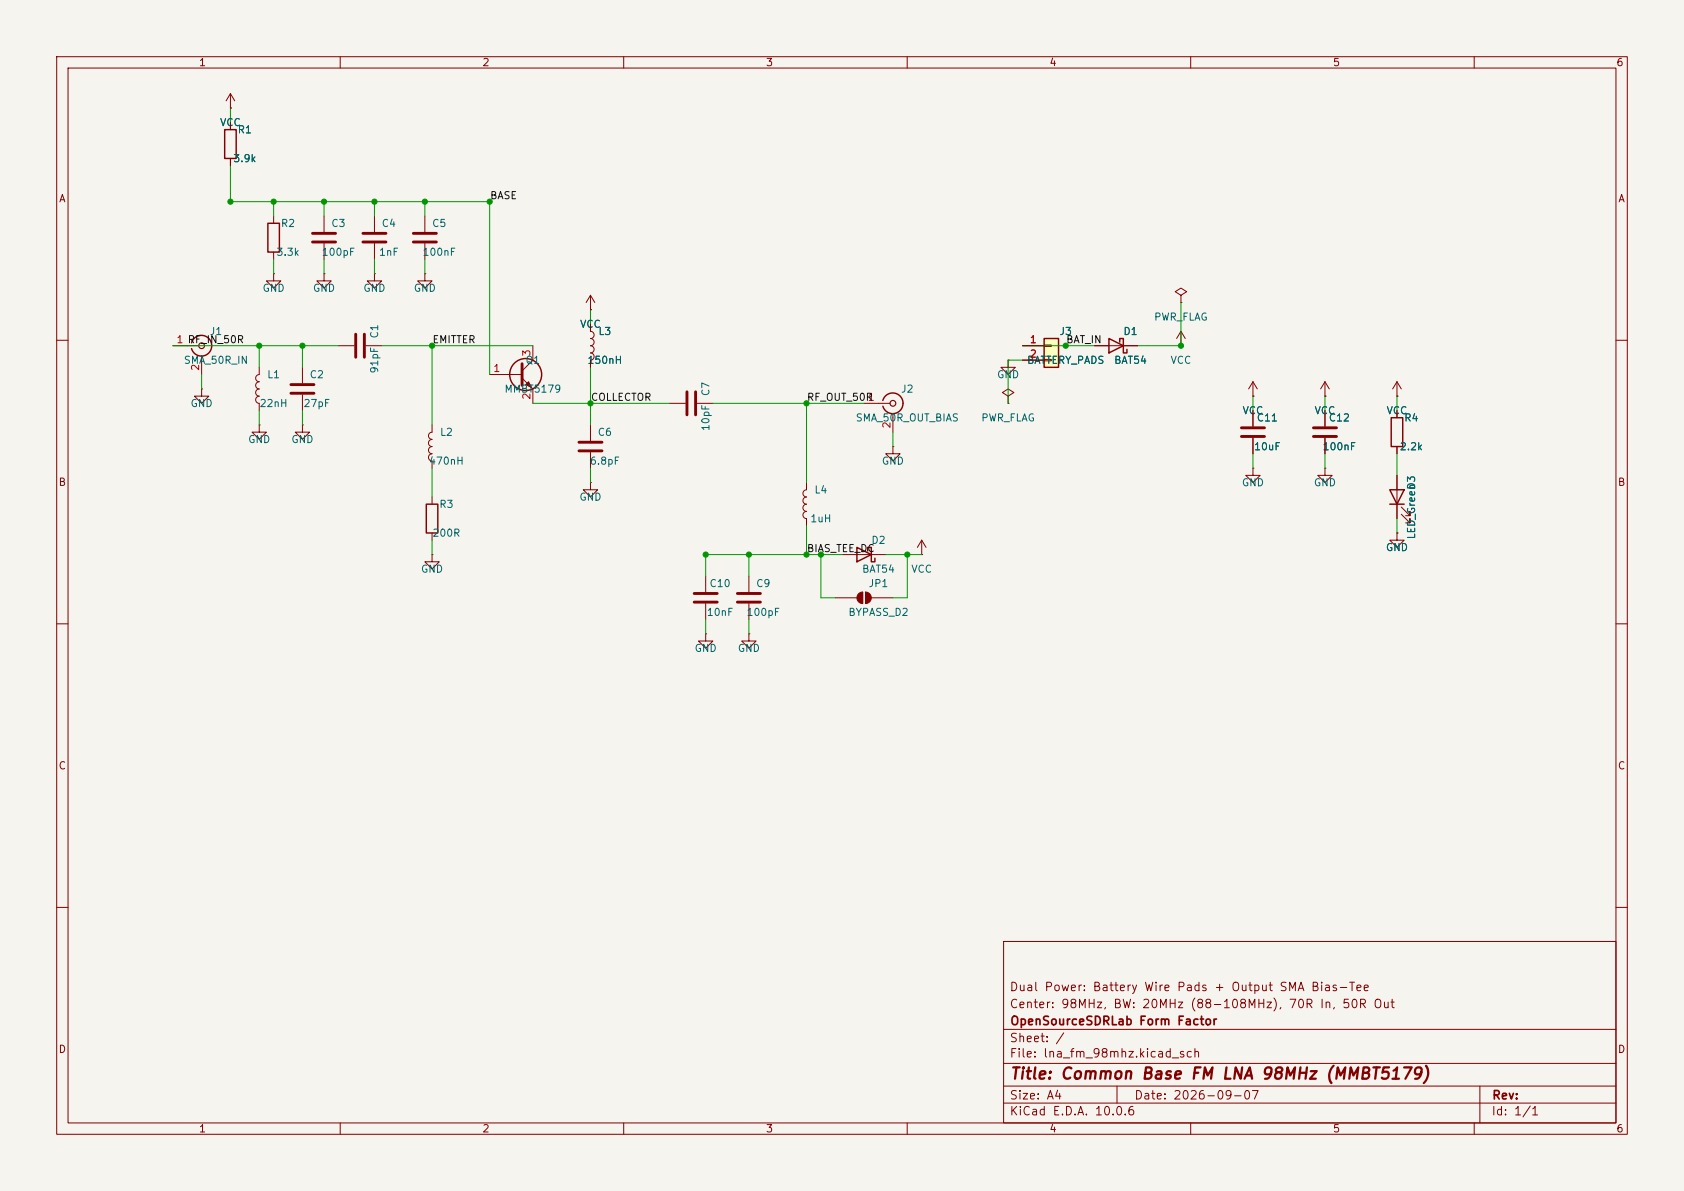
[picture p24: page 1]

Dual Power: Battery Wire Pads + Output SMA Bias-Tee
Center: 98MHz, BW: 20MHz (88-108MHz), 70R In, 50R Out
OpenSourceSDRLab Form Factor
Sheet: /
File: lna_fm_98mhz.kicad_sch
Title: Common Base FM LNA 98MHz (MMBT5179)

Size: A4 | Rev:
KiCad E.D.A. 10.0.6 | Id: 1/1

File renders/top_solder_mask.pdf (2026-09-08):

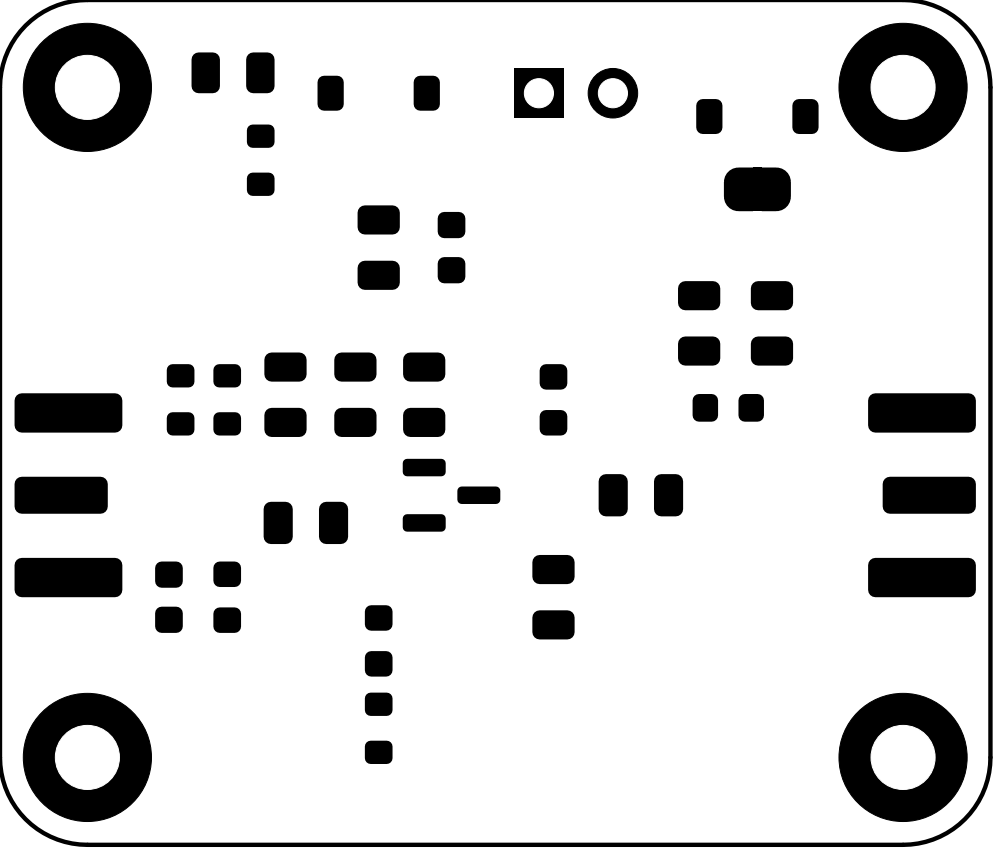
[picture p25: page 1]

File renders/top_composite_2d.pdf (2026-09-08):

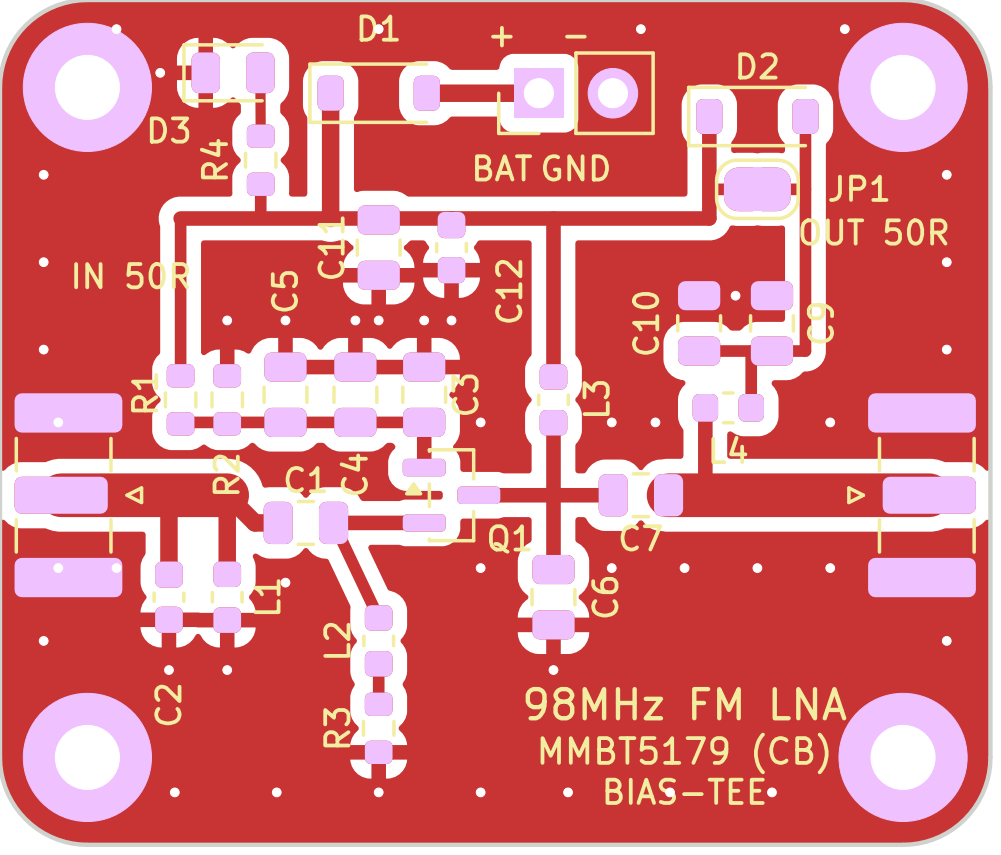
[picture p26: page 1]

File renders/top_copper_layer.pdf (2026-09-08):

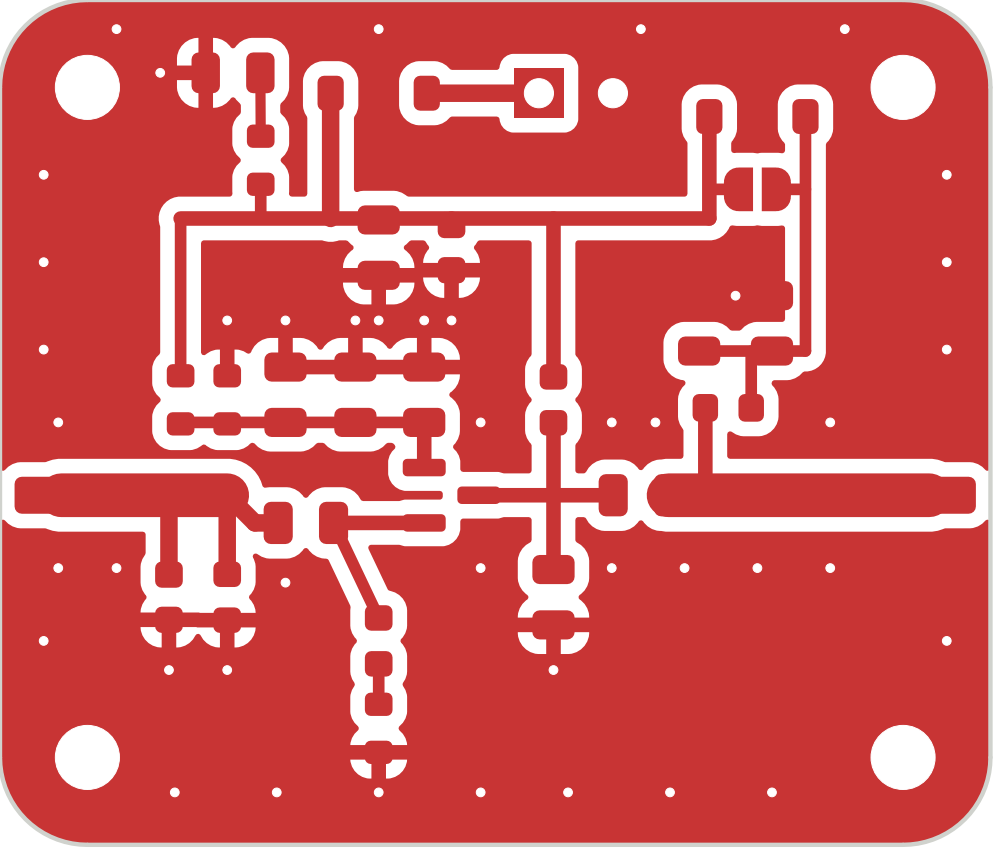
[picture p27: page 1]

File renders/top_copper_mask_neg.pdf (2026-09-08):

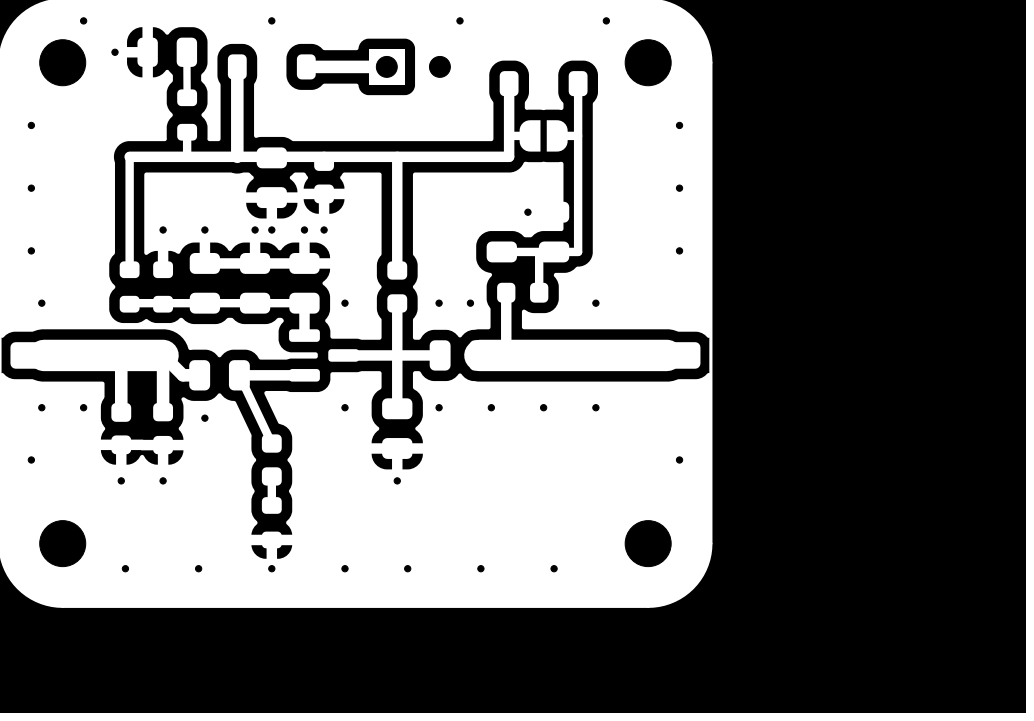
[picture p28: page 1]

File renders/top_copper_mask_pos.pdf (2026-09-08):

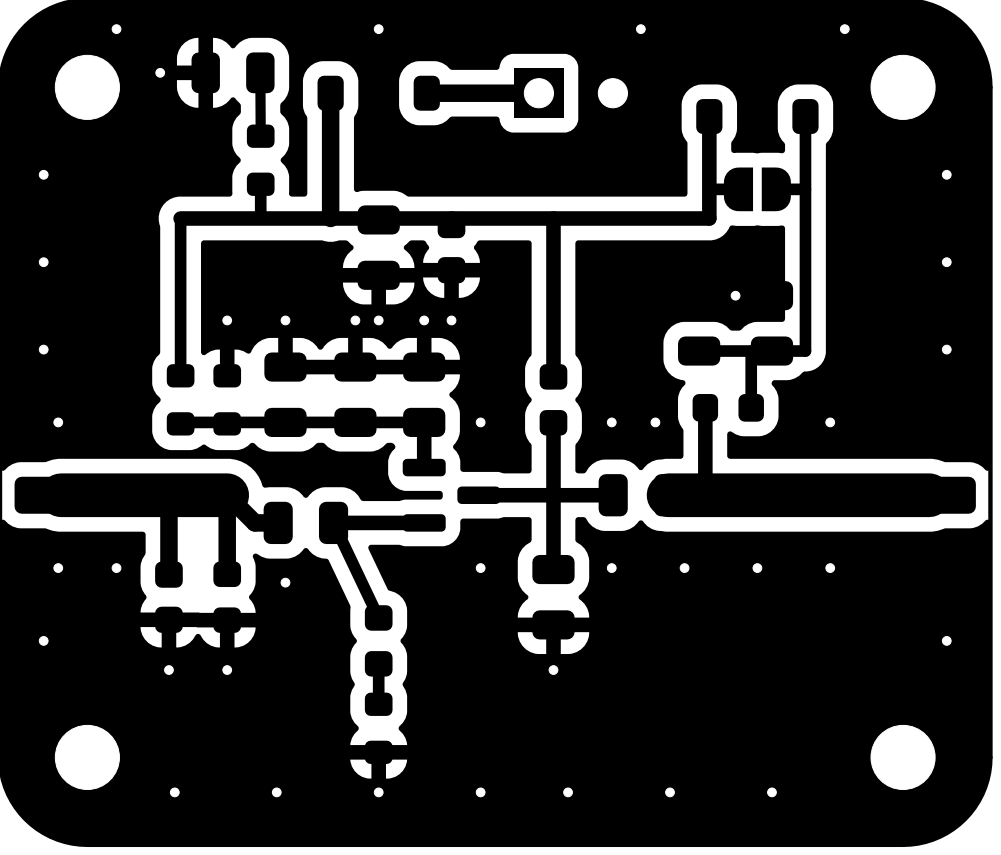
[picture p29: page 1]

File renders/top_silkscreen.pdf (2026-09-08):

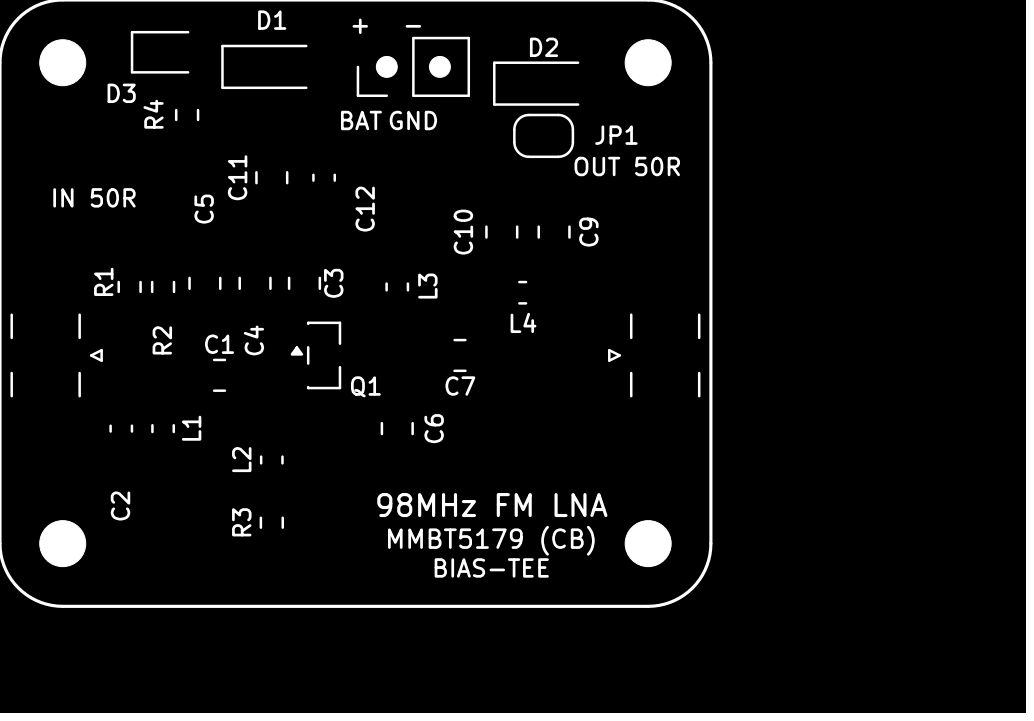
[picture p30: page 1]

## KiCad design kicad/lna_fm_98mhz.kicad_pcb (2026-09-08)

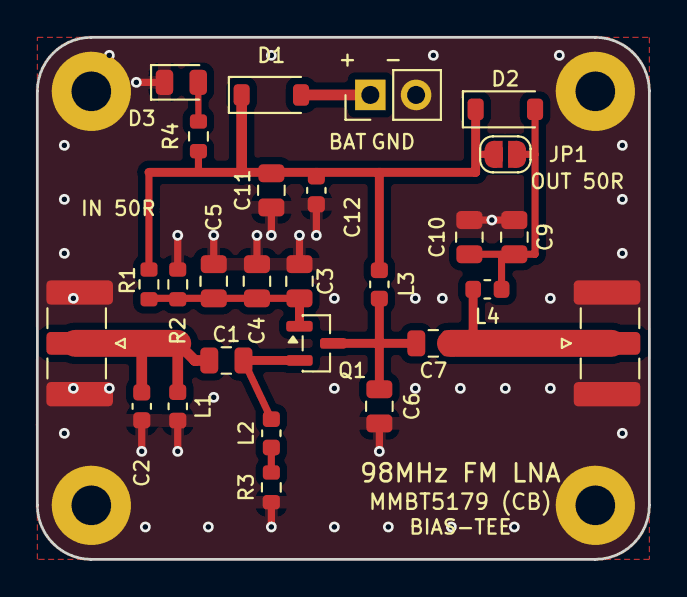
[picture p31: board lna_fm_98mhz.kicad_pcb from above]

Board: 2 copper layers, 34.0 x 29.0 mm, 31 parts (0 on the bottom side), 11 nets.

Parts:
C1: 91pF; C_0805_2012Metric
C2: 27pF; C_0603_1608Metric
C3, C9: 100pF; C_0805_2012Metric
C4: 1nF; C_0805_2012Metric
C5: 100nF; C_0805_2012Metric
C6: 6.8pF; C_0805_2012Metric
C7: 10pF; C_0805_2012Metric
C10: 10nF; C_0805_2012Metric
C11: 10uF; C_0805_2012Metric
C12: 100nF; C_0603_1608Metric
D1, D2: BAT54; D_SOD-123
D3: LED; LED_0805_2012Metric
H1, H2, H3, H4: M2; MountingHole_2.2mm_M2_Pad
J1: SMA_50R_IN; SMA_Samtec_SMA-J-P-H-ST-EM1_EdgeMount
J2: SMA_50R_OUT; SMA_Samtec_SMA-J-P-H-ST-EM1_EdgeMount
J3: BAT_PADS; PinHeader_1x02_P2.54mm_Vertical
JP1: SolderJumper_Open; SolderJumper-2_P1.3mm_Open_RoundedPad1.0x1.5mm
L1: 22nH; L_0603_1608Metric
L2: 470nH; L_0603_1608Metric
L3: 150nH; L_0603_1608Metric
L4: 1uH; L_0603_1608Metric
Q1: MMBT5179; SOT-23
R1: 3.9k; R_0603_1608Metric
R2: 3.3k; R_0603_1608Metric
R3: 200R; R_0603_1608Metric
R4: 2.2k; R_0603_1608Metric

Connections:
/BASE: C3.1, C4.1, C5.1, Q1.1, R1.1, R2.1
/BAT_IN: D1.2, J3.1
/BIAS_TEE_DC: C9.1, C10.1, D2.2, JP1.1, L4.2
/COLLECTOR: C6.1, C7.1, L3.1, Q1.3
/EMITTER: C1.2, L2.1, Q1.2
/RF_IN_50R: C1.1, C2.1, J1.1, L1.1
/RF_OUT_50R: C7.2, J2.1, L4.1
GND: C2.2, C3.2, C4.2, C5.2, C6.2, C9.2, C10.2, C11.2, C12.2, D3.1, H1.1, H2.1, H3.1, H4.1, J1.2, J2.2, J3.2, L1.2, R2.2, R3.2
unnamed: D3.2, R4.2
unnamed: L2.2, R3.1
VCC: C11.1, C12.1, D1.1, D2.1, JP1.2, L3.2, R1.2, R4.1

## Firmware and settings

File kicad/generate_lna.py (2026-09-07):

import sys
import uuid
from pathlib import Path

# Add kicad_mcp_server to path
sys.path.insert(0, r'D:\Programs\kicad-mcp-server\src')
from kicad_mcp_server.tools.schematic_editor import (
    _find_symbol_library_file,
    _extract_symbol_from_kicad_sym,
    _convert_symbol_to_lib_symbols_format,
)

def u():
    return str(uuid.uuid4())

def build_schematic(output_path: Path):
    needed_symbols = [
        ('Connector', 'Conn_Coaxial'),
        ('Device', 'C'),
        ('Device', 'L'),
        ('Device', 'R'),
        ('Device', 'LED'),
        ('Device', 'D_Schottky'),
        ('Transistor_BJT', 'Q_NPN_BEC'),
        ('Connector_Generic', 'Conn_01x02'),
        ('Jumper', 'SolderJumper_2_Open'),
        ('power', 'VCC'),
        ('power', 'GND'),
        ('power', 'PWR_FLAG'),
    ]

    lib_sym_blocks = []
    for lib, sym in needed_symbols:
        p = _find_symbol_library_file(lib)
        if not p:
            raise FileNotFoundError(f'Cannot find library {lib}')
        block = _extract_symbol_from_kicad_sym(p, sym)
        if not block:
            raise ValueError(f'Cannot find symbol {sym} in {lib}')
        conv = _convert_symbol_to_lib_symbols_format(block, lib, sym)
        lib_sym_blocks.append(conv)

    lib_symbols_str = '\n'.join(lib_sym_blocks)

    components = []
    wires = []
    labels = []
    power_symbols = []
    junctions = []

    def add_wire(x1, y1, x2, y2):
        wires.append(f'''\t(wire
\t\t(pts
\t\t\t(xy {x1:.2f} {y1:.2f}) (xy {x2:.2f} {y2:.2f})
\t\t)
\t\t(stroke
\t\t\t(width 0)
\t\t\t(type solid)
\t\t)
\t\t(uuid \x22{u()}\x22)
\t)''')

    def add_junction(x, y):
        junctions.append(f'''\t(junction (at {x:.2f} {y:.2f}) (diameter 0) (color 0 0 0 0) (uuid \x22{u()}\x22))''')

    def add_label(text, x, y, angle=0):
        justify = 'left' if angle in [0, 90] else 'right'
        labels.append(f'''\t(label \x22{text}\x22
\t\t(at {x:.2f} {y:.2f} {angle})
\t\t(fields_autoplaced yes)
\t\t(effects
\t\t\t(font
\t\t\t\t(size 1.27 1.27)
\t\t\t)
\t\t\t(justify {justify} bottom)
\t\t)
\t\t(uuid \x22{u()}\x22)
\t)''')

    def add_pwr(lib_id, x, y, angle=0):
        val = lib_id.split(':')[1]
        ref = f'#{val}_{len(power_symbols)+1}'
        power_symbols.append(f'''\t(symbol
\t\t(lib_id \x22{lib_id}\x22)
\t\t(at {x:.2f} {y:.2f} {angle})
\t\t(unit 1)
\t\t(exclude_from_sim no)
\t\t(in_bom yes)
\t\t(on_board yes)
\t\t(dnp no)
\t\t(uuid \x22{u()}\x22)
\t\t(property \x22Reference\x22 \x22{ref}\x22
\t\t\t(at {x:.2f} {y-2.54:.2f} 0)
\t\t\t(effects
\t\t\t\t(font (size 1.27 1.27))
\t\t\t\t(hide yes)
\t\t\t)
\t\t)
\t\t(property \x22Value\x22 \x22{val}\x22
\t\t\t(at {x:.2f} {y+2.54:.2f} 0)
\t\t\t(effects
\t\t\t\t(font (size 1.27 1.27))
\t\t\t)
\t\t)
\t\t(property \x22Footprint\x22 \x22\x22
\t\t\t(at {x:.2f} {y:.2f} 0)
\t\t\t(effects
\t\t\t\t(font (size 1.27 1.27))
\t\t\t\t(hide yes)
\t\t\t)
\t\t)
\t\t(pin \x221\x22 (uuid \x22{u()}\x22))
\t\t(instances
\t\t\t(project \x22lna_fm_98mhz\x22
\t\t\t\t(path \x22/\x22
\t\t\t\t\t(reference \x22{ref}\x22)
\t\t\t\t\t(unit 1)
\t\t\t\t)
\t\t\t)
\t\t)
\t)''')

    def add_comp(ref, val, lib_id, footprint, x, y, angle, pin_count):
        pins_str = '\n'.join([f'\t\t(pin \x22{i+1}\x22 (uuid \x22{u()}\x22))' for i in range(pin_count)])
        components.append(f'''\t(symbol
\t\t(lib_id \x22{lib_id}\x22)
\t\t(at {x:.2f} {y:.2f} {angle})
\t\t(unit 1)
\t\t(exclude_from_sim no)
\t\t(in_bom yes)
\t\t(on_board yes)
\t\t(dnp no)
\t\t(uuid \x22{u()}\x22)
\t\t(property \x22Reference\x22 \x22{ref}\x22
\t\t\t(at {x+2.54:.2f} {y-2.54:.2f} 0)
\t\t\t(effects
\t\t\t\t(font (size 1.27 1.27))
\t\t\t)
\t\t)
\t\t(property \x22Value\x22 \x22{val}\x22
\t\t\t(at {x+2.54:.2f} {y+2.54:.2f} 0)
\t\t\t(effects
\t\t\t\t(font (size 1.27 1.27))
\t\t\t)
\t\t)
\t\t(property \x22Footprint\x22 \x22{footprint}\x22
\t\t\t(at {x:.2f} {y:.2f} 0)
\t\t\t(effects
\t\t\t\t(font (size 1.27 1.27))
\t\t\t\t(hide yes)
\t\t\t)
\t\t)
{pins_str}
\t\t(instances
\t\t\t(project \x22lna_fm_98mhz\x22
\t\t\t\t(path \x22/\x22
\t\t\t\t\t(reference \x22{ref}\x22)
\t\t\t\t\t(unit 1)
\t\t\t\t)
\t\t\t)
\t\t)
\t)''')

    # 1. RF INPUT SECTION (Merged BPF & Match: Shunt LC Tank L1 || C2 + Series Capacitor C1)
    # J1 at (35.56, 60.96): Pin 1 (30.48, 60.96), Pin 2 (35.56, 66.04)
    add_comp('J1', 'SMA_50R_IN', 'Connector:Conn_Coaxial', 'Connector_Coaxial:SMA_Samtec_SMA-J-P-H-ST-EM1_EdgeMount', 35.56, 60.96, 0, 2)
    add_wire(35.56, 66.04, 35.56, 68.58)
    add_pwr('power:GND', 35.56, 68.58)

    # Wire from J1 to L1 tank junction at (45.72, 60.96)
    add_wire(30.48, 60.96, 45.72, 60.96)
    add_label('RF_IN_50R', 33.02, 60.96)
    add_junction(45.72, 60.96)

    # L1 (22nH shunt tank inductor to GND, 0603 wirewound) at (45.72, 68.58), angle 180:
    # Pin 1 at (45.72, 64.77), Pin 2 at (45.72, 72.39)
    add_comp('L1', '22nH', 'Device:L', 'Inductor_SMD:L_0603_1608Metric', 45.72, 68.58, 180, 2)
    add_wire(45.72, 60.96, 45.72, 64.77)
    add_wire(45.72, 72.39, 45.72, 74.93)
    add_pwr('power:GND', 45.72, 74.93)

    # C2 (27pF shunt tank capacitor to GND, 0603 C0G) at (53.34, 68.58), angle 180:
    # Pin 1 at (53.34, 64.77), Pin 2 at (53.34, 72.39)
    add_wire(45.72, 60.96, 53.34, 60.96)
    add_junction(53.34, 60.96)
    add_comp('C2', '27pF', 'Device:C', 'Capacitor_SMD:C_0603_1608Metric', 53.34, 68.58, 180, 2)
    add_wire(53.34, 60.96, 53.34, 64.77)
    add_wire(53.34, 72.39, 53.34, 74.93)
    add_pwr('power:GND', 53.34, 74.93)

    # C1 (91pF series match & DC block, 0805) at (63.50, 60.96), angle 90:
    # Pin 1 at (59.69, 60.96), Pin 2 at (67.31, 60.96)
    add_wire(53.34, 60.96, 59.69, 60.96)
    add_comp('C1', '91pF', 'Device:C', 'Capacitor_SMD:C_0805_2012Metric', 63.50, 60.96, 90, 2)
    # Wire from C1 Pin 2 to Emitter Node
    add_wire(67.31, 60.96, 76.20, 60.96)
    add_junction(76.20, 60.96)
    add_label('EMITTER', 76.20, 60.96)

    # 2. TRANSISTOR MMBT5179 (Q1)
    # Q1 at (91.44, 66.04), angle 0
    # Pin 1 (Base) is at (91.44 - 5.08, 66.04) = (86.36, 66.04)
    # Pin 2 (Emitter) is at (91.44 + 2.54, 66.04 - 5.08) = (93.98, 60.96)
    # Pin 3 (Collector) is at (91.44 + 2.54, 66.04 + 5.08) = (93.98, 71.12)
    add_comp('Q1', 'MMBT5179', 'Transistor_BJT:Q_NPN_BEC', 'Package_TO_SOT_SMD:SOT-23', 91.44, 66.04, 0, 3)
    # Wire from Emitter node (76.20, 60.96) to Q1 Pin 2 (93.98, 60.96)
    add_wire(76.20, 60.96, 93.98, 60.96)

    # Emitter Bias Choke L2 (470nH) + R3 (200R) down to GND:
    # At x = 76.20, drop down to L2:
    add_wire(76.20, 60.96, 76.20, 74.93)
    add_comp('L2', '470nH', 'Device:L', 'Inductor_SMD:L_0603_1608Metric', 76.20, 78.74, 180, 2)
    add_wire(76.20, 82.55, 76.20, 87.63)
    add_comp('R3', '200R', 'Device:R', 'Resistor_SMD:R_0603_1608Metric', 76.20, 91.44, 180, 2)
    add_wire(76.20, 95.25, 76.20, 97.79)
    add_pwr('power:GND', 76.20, 97.79)
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

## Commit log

2026-09-07 Initial release: 98 MHz FM Common-Base LNA (100% Agentic AI Designed)
    [lna_fm_98mhz-B_Courtyard.gbr, lna_fm_98mhz-B_Cu.gbl, lna_fm_98mhz-B_Fab.gbr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]
2026-09-07 Implement input bandpass pre-filter merged with input matching network
    - Merged parallel LC tank (L1=18nH || C2=47pF) at 50-ohm RF input with series C1=100pF DC block to emitter.
    - Suppresses out-of-band signals (<88 MHz shunted by L1, >108 MHz shunted by C2) while providing exact step-down transformation to low-impedance common-base emitter.
    - Preserves 98 MHz center performance: S21 = +19.88 dB, S11 = -22.27 dB (VSWR 1.17:1), Zin = 43.1 - j1.9 Ohm.
    - Updated Qucs simulation netlists, Touchstone s2p, and schematic generator scripts.
    - Updated KiCad schematic, zero ERC violations.
    - Synthesized PCB layout with C2 placed and routed, zero DRC errors.
    - Regenerated production Gerbers, Excellon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
    [lna_fm_98mhz-B_Courtyard.gbr, lna_fm_98mhz-B_Cu.gbl, lna_fm_98mhz-B_Fab.gbr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]
2026-09-07 Optimize input matching network for -31.87 dB return loss at 98 MHz
    - Parameter optimization: L1=22nH (0603 E12), C2=27pF (0603 E12), C1=91pF (0805 E24).
    - Restores real input resistance to 52.5 Ohm (from 43.1 Ohm) by tuning C1 transformation Q.
    - Improves S11 return loss from -22.27 dB to -31.87 dB (VSWR 1.05:1).
    - Preserves high gain (S21 = +19.91 dB) and out-of-band rejection (-19.9 dB at 50 MHz, +2.1 dB at 200 MHz).
    - Updated Qucs netlists, Touchstone s2p, and schematic generators.
    - Regenerated KiCad schematic and PCB layout with 0 ERC / 0 DRC violations.
    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
    [lna_fm_98mhz-B_Courtyard.gbr, lna_fm_98mhz-B_Cu.gbl, lna_fm_98mhz-B_Fab.gbr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]
2026-09-07 Update verification report timestamps
    [lna_fm_98mhz.kicad_pcb, lna_fm_98mhz.kicad_sch]
2026-09-07 Update printed schematic PDF with latest component values
2026-09-07 Regenerate production Gerbers with optimized BPF and package zip archive
    [lna_fm_98mhz-B_Courtyard.gbr, lna_fm_98mhz-B_Cu.gbl, lna_fm_98mhz-B_Fab.gbr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]
2026-09-07 Add component reference designators to silkscreen and update production Gerbers
    [lna_fm_98mhz-B_Cu.gbl, lna_fm_98mhz-B_Mask.gbs, lna_fm_98mhz-B_Paste.gbp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]
2026-09-07 Relocate D2, L2, R3 silkscreen labels and update all 2D/3D renders and SVGs
    [lna_fm_98mhz-B_Cu.gbl, lna_fm_98mhz-B_Mask.gbs, lna_fm_98mhz-B_Paste.gbp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]
2026-09-07 Relocate power header to 20mm and LED to (10mm, 2mm) with 0 DRC violations
    [lna_fm_98mhz-B_Cu.gbl, lna_fm_98mhz-B_Mask.gbs, lna_fm_98mhz-B_Paste.gbp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]
2026-09-07 Center power connector at 19mm in 15mm-23mm USB port cutout window
    [lna_fm_98mhz-B_Cu.gbl, lna_fm_98mhz-B_Mask.gbs, lna_fm_98mhz-B_Paste.gbp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]
2026-09-08 feat: 4-port openEMS 3D EM co-simulation, QUCS schematics, and enclosure 3D models
    [lna_fm_98mhz_assembly.step, lna_fm_98mhz_assembly.stl, lna_fm_98mhz_bare_board.stl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]
2026-09-08 fix(pcb): resize PCB to 34x29mm matching OpenSourceSDRLab enclosure
    - Compact PCB outline to 34.00 x 29.00 mm (X: [0, 34], Y: [0, 29])
    - Lower symmetrical RF centerline to Y = 14.50 mm
    - Set corner M2 mounting holes at (2.5, 2.5), (31.5, 2.5), (2.5, 26.5), (31.5, 26.5) mm
    - Re-route CPWG transmission lines, tuned output tank, and bias-tee
    - Rotate L4 choke horizontally to eliminate courtyard overlap
    - Verify KiCad DRC: 0 errors, 0 warnings, 0 unconnected items
    - Regenerate 3D mechanical models (bare board, full assembly, connector-free)
    - Re-render 2D photomasks, composite previews, and 3D raytraced renders
    - Update production Gerbers, Excellon drill files, and README specifications
    [lna_fm_98mhz-B_Cu.gbl, lna_fm_98mhz-B_Mask.gbs, lna_fm_98mhz-B_Paste.gbp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]
2026-09-08 feat(sim): full-board 4-port openEMS 3D FDTD and QUCS co-sim for 34x29mm PCB
2026-09-08 fix(pcb): update PCB outline to 34x29mm with R=3mm curved fillets matching h4m-keytop-24 enclosure
    - Redesign Edge.Cuts with 4x R=3.0mm concentric corner fillets matching enclosure posts
    - Align M2 mounting holes at (3.0, 3.0), (31.0, 3.0), (3.0, 26.0), (31.0, 26.0) mm
    - Set RF centerline to Y = 17.00 mm matching asymmetric enclosure SMA cutouts
    - Center DC power / battery header at X = 18.50 mm in the 7.6mm USB enclosure window
    - Verify KiCad DRC: 0 errors, 0 warnings, 0 unconnected items (drc_report.json)
    - Prove exact zero 3D interference in FreeCAD with h4m-keytop-24.step enclosure
    - Re-export 3D deliverables: assembly, bare board, and connector-free STEP & STL models
    - Re-run openEMS fu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
    [h4m-keytop-24.step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]
2026-09-08 feat(render): add 3D raytraced renders of PCB assembled into h4m-keytop-24 enclosure and combined STEP/STL models
    [lna_fm_98mhz_in_enclosure.step, lna_fm_98mhz_in_enclosure.stl]
2026-09-08 chore: add h4m_case.stl model
    [h4m_case.stl]
2026-09-08 chore: clean up obsolete renders and legacy simulation files from earlier revisions
    [lna_fm_98mhz.step]
2026-09-08 docs: update README for 34x29mm layout, openEMS 3D EM co-simulation, and add enclosure lid files
    [h4m-keytop-25.step, h4m_lid.stl, lna_fm_98mhz_enclosure_with_lid.step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]
2026-09-08 docs: credit pop aruaru on Printables.com for enclosure CAD models
2026-09-08 refactor: move enclosure 3D files to dedicated enclosure/ folder
    [h4m-keytop-24.step, h4m-keytop-25.step, h4m_case.stl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]
2026-09-08 refactor: reorganize project into modular subdirectories (kicad, qucs-sim, openems, freecad, docs)
    [lna_fm_98mhz-B_Cu.gbr, lna_fm_98mhz-B_Mask.gbr, lna_fm_98mhz-B_Paste.gbr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]
2026-09-08 feat: complete KiCad -> FreeCAD -> FreeCAD-Microwave -> Qucs-S pipeline with master orchestrator
    [lna_fm_98mhz_microwave.FCStd]
